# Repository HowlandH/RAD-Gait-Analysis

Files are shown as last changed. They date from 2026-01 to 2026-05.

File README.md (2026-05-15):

# RAD — Running Analysis Device

An affordable (<$60) foot-mounted wearable that tracks running gait metrics in real time and transmits data via Bluetooth Low Energy to an iOS companion app. Built for recreational runners and high school athletes who cannot access professional lab gait analysis ($350-500/session).

**Team:** Hudson Howland and Brantley Field — PLTW Engineering Capstone

---

## Project Status — COMPLETE

| Phase | Status |
|---|---|
| Hardware Assembly | COMPLETE |
| IMU Data Acquisition | COMPLETE |
| Gait Detection Firmware | COMPLETE |
| BLE Communication | COMPLETE |
| iOS Companion App | COMPLETE |
| Enclosure Design & Print | COMPLETE |
| System Integration | COMPLETE |
| Mounting Angle Calibration | COMPLETE |
| Field Testing | COMPLETE |
| Stakeholder Evaluation | COMPLETE |

---

## Hardware

| Component | Part | Cost |
|---|---|---|
| Microcontroller | Arduino Nano 33 BLE Rev2 | ~$25 |
| IMU Sensor | MPU-6050 (GY-521) | ~$3 |
| Power Module | DFRobot MP2636 | ~$10 |
| Battery | 3.7V 700mAh LiPo | ~$8 |
| Enclosure | 3D printed PLA | ~$2 |
| **Total BOM** | | **~$55** |

Enclosure dimensions: 50mm x 40mm x 20mm. Mounts to shoe laces via elastic strap. Snap-fit two-part design.

### Wiring

```
MPU-6050 → Arduino Nano 33 BLE Rev2
  VCC → 3.3V
  GND → GND
  SCL → A5
  SDA → A4

MP2636 Power Module
  VOUT (SYS pin) → Arduino VIN
  GND → Arduino GND
  BAT+ → LiPo red wire
  BAT- → LiPo black wire
  Micro-USB port = charging input only
```

---

## Firmware

Located in `gait_tracker/`. Written in C++ for Arduino Nano 33 BLE Rev2.

### Architecture

| File | Responsibility |
|---|---|
| `gait_tracker.ino` | Main 100Hz loop |
| `config.h` | All constants and thresholds |
| `imu_sensor.h/.cpp` | MPU-6050 init, complementary filter, pitch tracking, mounting angle calibration |
| `gait_detection.h/.cpp` | Foot strike peak detection and heel/midfoot/forefoot classification |
| `stride_length.h/.cpp` | Inverted pendulum stride estimation |
| `cadence.h/.cpp` | Circular buffer cadence calculation |
| `ble_comms.h/.cpp` | ArduinoBLE GATT service and characteristic updates |
| `power_mgmt.h/.cpp` | Battery voltage monitoring |

### Key Algorithms

**Strike detection:** Peak detection on Z-axis acceleration with 200ms debounce. Threshold: 1.5g.

**Strike classification:** Pitch angle at moment of impact:
- Heel: pitch < -15 degrees
- Midfoot: -15 to +5 degrees
- Forefoot: pitch > +5 degrees

**Mounting angle calibration:** On every boot, the firmware samples the device's resting pitch for 3 seconds while mounted on the shoe and stores it as an offset. All subsequent pitch readings subtract this offset so classification thresholds work correctly regardless of mounting angle or shoe geometry.

**Stride length:** Inverted pendulum model: `stride = 4 x legLength x sin(angle/2)`

**Cadence:** Circular buffer of last 30 strike timestamps. Requires 3 minimum strikes before reporting.

### BLE Characteristics

```
Service:     19b10000-e8f2-537e-4f6c-d104768a1214
Stride:      19b10001 (Float, 4 bytes)
Cadence:     19b10002 (UInt16, 2 bytes)
Strike type: 19b10003 (UInt8: 0=Heel, 1=Mid, 2=Fore)
Battery:     00002a19 (UInt8, standard)
```

### Setup

1. Install Arduino IDE
2. Install libraries: ArduinoBLE, Adafruit MPU6050, Adafruit Unified Sensor
3. Open `gait_tracker/gait_tracker.ino`
4. Select board: Arduino Nano 33 BLE
5. Upload — calibration runs automatically on boot

---

## iOS App (GaitTrackerX)

Located in `GaitTrackerX/`. Built in Swift/SwiftUI. Active Xcode project: `GaitTrackerX/GaitTrackerX.xcodeproj`.

### Screens

**Connection Screen** — scans for and connects to the Arduino device with animated BLE pulse rings.

**Live Dashboard** — cadence hero card with color feedback (red/orange/green/blue by performance zone), stride length, distance, duration, pace, and strike type displayed live. Start, pause, and stop run controls.

**Run History** — all past runs with bar charts for cadence trend and distance (last 7 runs) and a donut chart for overall strike type distribution.

**Run Detail** — full metrics for any past run including per-step strike distribution donut chart with counts and percentages, and a cadence analysis bar showing position on the 140-200 spm scale with the 170-180 optimal zone highlighted.

**Share Card** — generates a shareable PNG with dark navy/purple gradient design showing distance, cadence, steps, duration, and strike type.

**Settings** — leg length slider (affects stride calculation), imperial/metric toggle, delete history.

### Key Files

| File | Responsibility |
|---|---|
| `GaitTrackerApp.swift` | App entry point |
| `Managers/BLEManager.swift` | CoreBluetooth scanning, connection, characteristic parsing |
| `Managers/DataManager.swift` | Run history persistence via UserDefaults + JSONEncoder |
| `Models/RunSession.swift` | Active run timer and step accumulation |
| `Models/GaitMetrics.swift` | StrikeType enum and GaitMetrics struct |
| `Views/ConnectionView.swift` | BLE scanning UI |
| `Views/DashboardView.swift` | Live metrics and run controls |
| `Views/HistoryView.swift` | Run history and charts |
| `Views/RunDetailView.swift` | Per-run detailed metrics and graphs |
| `Views/RunSummaryCard.swift` | Shareable PNG card renderer |
| `Views/SettingsView.swift` | User preferences |

---

## Field Testing Results

**Test conducted:** Half-mile walk test, May 1, 2026

| Metric | Result |
|---|---|
| Distance recorded | 1.40 km (actual: 0.84 km, 67% overestimate) |
| Steps counted | 1,157 |
| Duration | 14:10 |
| Cadence | 74 spm |
| Strike classification | Nearly 100% forefoot (caused by mounting angle) |

**Issues identified and resolved:**

1. Forefoot classification bias — the device mounted at a forward angle on the shoe added a static pitch offset that pushed every strike above the +5 degree forefoot threshold. Fixed by adding automatic mounting angle calibration to the firmware startup routine.

2. Stride length overestimation — the inverted pendulum model is calibrated for running gait, not walking. The `STRIDE_CORRECTION_FACTOR` in `config.h` is set to 1.0 and should be tuned against measured track data at running pace.

---

## Stakeholder Evaluation

Feedback gathered from three evaluators:

**Jackson — Peer / Athlete :** Validated the core concept. Suggested adding padding to the enclosure and rounding the corners for comfort. Conditionally willing to use and recommend the device once accuracy is demonstrated.

**Trey — Software Engineer:** Called it an impressive first prototype. Approved of the real-time plus historical data display approach. Raised questions about data privacy and storage that were addressed: all data is stored locally on the user's iPhone with no cloud connection or external transmission.

**Diana — Competitive Runner / Junior Olympic Athlete:** Endorsed the concept for high school runners who cannot afford professional alternatives. Recommended moving to lace mounting over ankle mounting at race pace. Requested accuracy validation against a known device before full endorsement.

---

## Design Specifications

| Priority | Specification | Status |
|---|---|---|
| 1 (Cost) | BOM under $60 | MET — ~$55 |
| 2 (Functionality) | Cadence within 3 spm accuracy | Pending running field test |
| 3 (Size) | Enclosure max 50x40x20mm | MET |
| 4 (Data Rate) | Minimum 100Hz sampling | MET |
| 5 (Battery) | Minimum 3 hours continuous | Pending test |
| 6 (Durability) | IPX3 moisture resistance | Pending test |

---

## Repository Structure

```
RAD-Gait-Analysis/
├── gait_tracker/              # Arduino firmware (active)
│   ├── gait_tracker.ino
│   ├── config.h
│   ├── imu_sensor.h/.cpp      # Includes mounting angle calibration
│   ├── gait_detection.h/.cpp
│   ├── stride_length.h/.cpp
│   ├── cadence.h/.cpp
│   ├── ble_comms.h/.cpp
│   ├── power_mgmt.h/.cpp
│   └── README.md
├── GaitTrackerX/              # iOS app (active Xcode project)
│   └── GaitTrackerX.xcodeproj
├── docs/
│   ├── breadboard_layout.md
│   └── datasheets/
├── test_sketches/             # Standalone hardware test sketches
├── RAD_Project_Briefing.md    # Full project context document
├── CHANGELOG.md
└── README.md
```

---

## Authors

Hudson Howland and Brantley Field — PLTW Engineering Capstone, 2026

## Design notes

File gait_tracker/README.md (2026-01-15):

# Gait Tracker - Arduino Firmware

Arduino firmware for the running gait analysis device.

## Hardware Requirements

- Arduino Nano 33 BLE Rev2
- MPU-6050 6-axis IMU
- MP2636 Power Booster & Charger Module
- 3.7V 700mAh LiPo Battery

## Wiring

```
MPU-6050 → Arduino Nano 33 BLE Rev2
  VCC → 3.3V
  GND → GND
  SCL → A5 (SCL)
  SDA → A4 (SDA)

MP2636 Power Module → Arduino Nano
  5V OUT → VIN
  GND → GND

LiPo Battery → MP2636
  + → BAT+
  - → BAT-
```

## Required Libraries

Install these libraries via Arduino Library Manager:

1. **ArduinoBLE** - For Bluetooth Low Energy communication
2. **Adafruit MPU6050** - For IMU sensor interface
3. **Adafruit Sensor** - Dependency for MPU6050 library
4. **Wire** - I2C communication (built-in)

## Installation

1. Open `gait_tracker.ino` in Arduino IDE
2. Select board: **Arduino Nano 33 BLE** (Tools → Board)
3. Install required libraries
4. Uncomment library includes in relevant files:
   - `imu_sensor.cpp` - MPU6050 library
   - `ble_comms.cpp` - ArduinoBLE library
5. Upload to board

## Configuration

Edit `config.h` to adjust:

- Strike detection threshold
- Cadence buffer size
- BLE service UUIDs
- Battery voltage divider ratio
- Debug mode settings

## Module Overview

### imu_sensor.h/cpp
- Initializes MPU-6050
- Reads accelerometer and gyroscope at 100Hz
- Applies complementary filter for orientation
- Tracks pitch/roll angles and swing angle

### gait_detection.h/cpp
- Detects foot strikes via Z-axis acceleration peaks
- Classifies strike type (heel/midfoot/forefoot) based on pitch angle
- Implements stride state machine

### stride_length.h/cpp
- Estimates stride length using inverted pendulum model
- Formula: `stride_length = 4 * h * sin(θ/2)`
- Supports leg length calibration

### cadence.h/cpp
- Tracks steps per minute using circular buffer
- Maintains rolling average over last 30 strikes
- Target accuracy: ±3 steps/min

### ble_comms.h/cpp
- Advertises as "GaitTracker"
- Implements GATT characteristics for metrics
- Handles connection/disconnection events

### power_mgmt.h/cpp
- Monitors battery voltage via analog pin
- Calculates battery percentage
- Supports low-power mode (TODO)

## Testing

### I2C Scanner Test
Run I2C scanner sketch to verify MPU-6050 at address `0x68`

### Serial Monitor
Set baud rate to **115200** for debug output

### Desktop Testing
1. Tap device on desk at known cadence (use metronome app)
2. Verify strike detection in serial output
3. Tilt device during taps to test strike classification

### BLE Testing
Use "nRF Connect" iOS app to:
- Scan for "GaitTracker" device
- Connect and view characteristics
- Subscribe to notifications

## Calibration

1. Place device on flat surface
2. Power on - calibration runs automatically
3. Verify serial output shows gyroscope offsets
4. Expected accelerometer: Z ≈ 1g, X/Y ≈ 0g

## Troubleshooting

**MPU-6050 not detected:**
- Check I2C wiring (SDA/SCL)
- Run I2C scanner sketch
- Verify 3.3V power connection

**BLE not advertising:**
- Ensure ArduinoBLE library is installed
- Check Serial Monitor for error messages
- Verify board is Arduino Nano 33 BLE Rev2

**Inaccurate strike detection:**
- Adjust `STRIKE_THRESHOLD` in config.h
- Check IMU mounting orientation
- Verify device is secured to shoe

## Next Steps

1. Complete Phase 1: Hardware verification
2. Install required libraries and uncomment includes
3. Test with breadboard setup
4. Proceed to field testing once stable

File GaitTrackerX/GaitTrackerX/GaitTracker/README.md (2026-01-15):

# GaitTracker iOS App

iOS companion app for the running gait tracker device.

## Requirements

- Xcode 14.0+
- Swift 5.7+
- iOS 15.0+
- Physical iOS device (BLE doesn't work in Simulator)

## Project Structure

```
GaitTracker/
├── GaitTrackerApp.swift       # App entry point
├── Views/
│   ├── ConnectionView.swift   # BLE scanning/pairing
│   ├── DashboardView.swift    # Real-time metrics display
│   ├── HistoryView.swift      # Past runs
│   └── SettingsView.swift     # Configuration
├── Models/
│   ├── GaitMetrics.swift      # Data structures
│   └── RunSession.swift       # Run management
├── Managers/
│   ├── BLEManager.swift       # CoreBluetooth wrapper
│   └── DataManager.swift      # Persistence (Core Data)
└── Resources/
    └── Info.plist             # App configuration
```

## BLE Service Specification

### Service UUID
`19b10000-e8f2-537e-4f6c-d104768a1214`

### Characteristics

| Characteristic | UUID | Type | Properties | Description |
|---|---|---|---|---|
| Stride Length | `19b10001-...` | Float (4 bytes) | Read, Notify | Meters |
| Cadence | `19b10002-...` | Uint16 (2 bytes) | Read, Notify | Steps/min |
| Strike Type | `19b10003-...` | Uint8 (1 byte) | Read, Notify | 0=Heel, 1=Mid, 2=Forefoot |
| Battery Level | `00002a19-...` | Uint8 (1 byte) | Read, Notify | Percentage (0-100) |

## Setup Instructions

### 1. Create New Project
1. Open Xcode
2. Create new SwiftUI App project
3. Set minimum deployment target to iOS 15.0
4. Enable CoreBluetooth capability

### 2. Configure Info.plist
Add Bluetooth permissions:
```xml
<key>NSBluetoothAlwaysUsageDescription</key>
<string>This app needs Bluetooth to connect to your GaitTracker device</string>
<key>NSBluetoothPeripheralUsageDescription</key>
<string>This app needs Bluetooth to communicate with your running tracker</string>
```

### 3. Implement BLEManager
```swift
import CoreBluetooth
import Combine

class BLEManager: NSObject, ObservableObject {
    @Published var isScanning = false
    @Published var isConnected = false
    @Published var discoveredDevices: [CBPeripheral] = []
    @Published var currentMetrics = GaitMetrics()

    private var centralManager: CBCentralManager!
    private var connectedPeripheral: CBPeripheral?

    // Service and Characteristic UUIDs
    let gaitServiceUUID = CBUUID(string: "19b10000-e8f2-537e-4f6c-d104768a1214")
    // ... add characteristic UUIDs
}
```

## Key Features

### Dashboard View
- Large cadence display (primary metric)
- Stride length with running average
- Color-coded foot strike indicator:
  - Red = Heel strike (higher impact)
  - Yellow = Midfoot strike (moderate)
  - Green = Forefoot strike (lower impact)
- Distance counter (stride × steps)
- Run timer
- Battery indicator

### Run History
- List of completed runs
- Summary statistics per run
- Charts showing metrics over time
- Tap to view detailed breakdown

### Settings
- **Leg Length Calibration** - Input for stride calculation
- **Units** - Toggle metric/imperial
- **Data Export** - Share runs as CSV

## Data Models

### GaitMetrics
```swift
struct GaitMetrics {
    var strideLength: Float = 0.0      // meters
    var cadence: Int = 0               // steps/min
    var strikeType: StrikeType = .mid
    var batteryLevel: Int = 100        // percentage
    var distance: Float = 0.0          // cumulative meters
    var duration: TimeInterval = 0     // seconds
}

enum StrikeType: UInt8 {
    case heel = 0
    case midfoot = 1
    case forefoot = 2
}
```

### RunSession
```swift
class RunSession: ObservableObject {
    @Published var isActive = false
    @Published var metrics = GaitMetrics()

    var startTime: Date?
    var stepCount: Int = 0

    func start() { }
    func pause() { }
    func stop() { }
    func save() { }
}
```

## Testing

### With nRF Connect App
Before building the full app, test BLE communication:
1. Download "nRF Connect" from App Store
2. Scan for "GaitTracker" device
3. Connect and view services
4. Subscribe to characteristics
5. Verify notifications update correctly

### With Physical Device
1. Build and run on iPhone
2. Power on Arduino device
3. Tap "Scan" in app
4. Connect to "GaitTracker"
5. Simulate foot strikes (tap device on desk)
6. Verify metrics update in real-time

## Development Tasks (Phase 5)

- [ ] Create SwiftUI project
- [ ] Implement BLEManager with CoreBluetooth
- [ ] Create GaitMetrics and RunSession models
- [ ] Build ConnectionView with device scanning
- [ ] Build DashboardView with real-time display
- [ ] Test connection and data parsing
- [ ] Handle disconnect/reconnect gracefully
- [ ] Add error handling and user feedback

## Future Enhancements (Phase 9)

- [ ] Implement HistoryView with Core Data
- [ ] Add SettingsView with calibration
- [ ] Create data visualization charts
- [ ] Implement CSV export
- [ ] Add haptic feedback on strikes
- [ ] Improve UI/UX polish

## Notes

- BLE requires physical iOS device (doesn't work in Simulator)
- Test with Arduino device powered on and advertising
- Connection may take 5-10 seconds initially
- Ensure UUIDs match between firmware and app
- Handle all BLE callbacks on main thread for UI updates

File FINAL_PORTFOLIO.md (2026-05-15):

# Final Portfolio — RAD: Running Analysis Device

**Team:** Hudson Howland and Brantley Field
**Class:** PLTW Engineering Capstone
**Date:** May 2026

---

## 1. Problem Statement

79% of recreational runners are injured each year, and 50-70% of those injuries are overuse injuries directly linked to poor running biomechanics. The primary correctable factor is cadence — the number of steps per minute. Research shows that a 5-10% increase in cadence significantly reduces knee and hip loading. Yet 60% of high school cross-country runners surveyed did not know their own cadence, and 75% expressed concern about past or future injury.

Professional gait analysis costs $350-500 per session and is not accessible to most runners. Existing wearable alternatives either cost $200 or more, use metrics that most runners do not understand, or are no longer available on the market. There is no affordable, accessible solution built specifically for high school athletes and recreational runners.

RAD — the Running Analysis Device — is our solution.

---

## 2. Project Proposal and Design Goals

RAD is a foot-mounted wearable that tracks running gait metrics in real time and sends data wirelessly to an iPhone via Bluetooth Low Energy. It is designed to cost under $60 total and be usable by any runner without any prior technical knowledge.

### Design Specifications

| Priority | Specification | Target |
|---|---|---|
| 1 | Total BOM cost | Under $60 |
| 2 | Cadence accuracy | Within 3 steps/min |
| 3 | Enclosure size | Max 50mm x 40mm x 20mm |
| 4 | Sampling rate | Minimum 100Hz |
| 5 | Battery life | Minimum 3 hours |
| 6 | Moisture resistance | IPX3 |

### Metrics to Track

- Cadence (steps per minute)
- Stride length (meters per step)
- Foot strike type (Heel / Midfoot / Forefoot)
- Distance (cumulative)
- Battery level

---

## 3. Hardware

### Bill of Materials

| Component | Part | Cost |
|---|---|---|
| Microcontroller | Arduino Nano 33 BLE Rev2 | ~$25 |
| IMU Sensor | MPU-6050 (GY-521) | ~$3 |
| Power Module | DFRobot MP2636 | ~$10 |
| Battery | 3.7V 700mAh LiPo | ~$8 |
| Enclosure | 3D printed PLA | ~$2 |
| **Total** | | **~$55** |

Design specification met: BOM is under $60.

### Wiring

```
MPU-6050 → Arduino Nano 33 BLE Rev2
  VCC → 3.3V
  GND → GND
  SCL → A5
  SDA → A4

MP2636 Power Module
  VOUT → Arduino VIN (5V regulated)
  GND → Arduino GND
  BAT+ → LiPo red wire
  BAT- → LiPo black wire
  Micro-USB port = charging input only
```

### Enclosure

3D printed in blue PLA. Dimensions: 50mm x 40mm x 20mm (meets design spec). Snap-fit two-part design for easy access to internals. Mounts to shoe laces via elastic strap.

---

## 4. Firmware

Written in C++ for Arduino Nano 33 BLE Rev2. Modular architecture across 6 files.

### How It Works

**Step 1 — Startup calibration:** The device samples the IMU for approximately 3 seconds on boot. First it removes gyroscope bias by averaging 100 samples at rest. Then it warms up the pitch filter and records the device's resting pitch angle from the shoe mounting position. This offset is stored and subtracted from all future pitch readings so classification thresholds work correctly regardless of how the device sits on the shoe.

**Step 2 — 100Hz sampling loop:** The main loop runs every 10ms. Each cycle reads the MPU-6050 accelerometer and gyroscope and updates the pitch angle estimate using a complementary filter (96% gyroscope, 4% accelerometer).

**Step 3 — Foot strike detection:** When Z-axis acceleration exceeds 1.5g and begins to decelerate, a foot strike is recorded. A 200ms debounce window prevents double-counting.

**Step 4 — Strike classification:** At the moment of impact, the corrected pitch angle determines strike type:
- Heel: below -15 degrees
- Midfoot: -15 to +5 degrees
- Forefoot: above +5 degrees

**Step 5 — Stride length:** The maximum swing angle during each stride is tracked. At each foot strike, stride length is calculated using the inverted pendulum model: `stride = 4 x legLength x sin(angle/2)`.

**Step 6 — Cadence:** A circular buffer stores the timestamps of the last 30 foot strikes. Cadence is calculated from the span of those timestamps. A minimum of 3 strikes is required before cadence is reported.

**Step 7 — BLE transmission:** After each foot strike, four BLE characteristics are updated: stride length (Float), cadence (UInt16), strike type (UInt8), and battery level (UInt8). The iPhone app receives these notifications in real time.

---

## 5. iOS App (GaitTracker)

Built in Swift/SwiftUI. Runs on iPhone via Bluetooth. Tested on physical hardware.

### Connection Screen
Scans for nearby Arduino devices. Animated pulsing rings provide visual feedback while scanning.

### Live Dashboard
Displays cadence, stride length, distance, duration, pace, and strike type in real time. The cadence card changes color based on performance: red (below 160 spm), orange (160-169), green (170-180 optimal), blue (above 180). Run start, pause, and stop controls.

### Run History
Shows all past runs as cards. Bar charts display cadence trend and distance for the last 7 runs. A donut chart shows overall strike type distribution across all saved runs. Charts appear automatically once 2 or more runs exist.

### Run Detail
Opens from any run card. Shows all metrics for that run. Includes a per-step strike distribution donut chart with step counts and percentages, and a cadence analysis bar that shows where the run falls on a 140-200 spm scale with the 170-180 optimal zone highlighted in green.

### Share Card
Generates a shareable PNG image for each run. Dark navy and purple gradient design. Shows distance, cadence, steps, duration, and strike type. Shared via the iOS system share sheet.

### Settings
Leg length slider from 0.6 to 1.1 meters (affects stride calculation accuracy). Imperial and metric unit toggle. Delete all history option.

---

## 6. Testing Results

### Field Test — Half-Mile Walk Test, May 1, 2026

| Metric | Recorded | Actual | Notes |
|---|---|---|---|
| Distance | 1.40 km | 0.84 km | 67% overestimate |
| Steps | 1,157 | — | Confirmed counting |
| Duration | 14:10 | — | Confirmed timing |
| Cadence | 74 spm | — | Expected for walking |
| Strike type | 100% Forefoot | Mixed | Mounting angle bias |

### Issues Found and Resolved

**Issue 1 — Forefoot classification bias**
The device was mounted at a forward angle on the shoe, adding a static pitch offset that pushed every detected pitch reading above the +5 degree forefoot threshold. Every step was classified as forefoot regardless of actual strike type.

Resolution: A mounting angle calibration routine was added to the firmware startup. The device now automatically measures its resting pitch angle when mounted on the shoe and subtracts that offset from all subsequent readings. This runs on every boot with no user input required.

**Issue 2 — Stride length overestimation**
The inverted pendulum model overestimated distance by approximately 67% during the walk test. The `STRIDE_CORRECTION_FACTOR` constant in the firmware is set to 1.0 and has not been tuned against real data.

Resolution: This requires a measured running test on a track of known distance. The correction factor should be adjusted until the device output matches the true distance. This is planned as the next field test.

### Design Specification Status

| Specification | Status |
|---|---|
| BOM under $60 | MET — approximately $55 |
| Enclosure max 50x40x20mm | MET |
| 100Hz sampling rate | MET |
| Cadence within 3 spm | Pending running field test |
| Battery minimum 3 hours | Pending test |
| IPX3 moisture resistance | Pending test |

---

## 7. Stakeholder Evaluation

Three external evaluators reviewed the prototype and provided structured feedback.

### Jackson — Peer / Cross-Country Runner

Validated the core concept, saying the device would help runners know when they are doing well or poorly, which would help change running form for the better. Primary concern was the physical enclosure — recommended adding padding and rounding the corners so it does not feel like a plastic box on the ankle. Willing to use and recommend the device once accuracy is demonstrated.

### Trey — Software Engineer

Called it an impressive first prototype and approved the data display approach of real-time metrics plus historical trend graphs. Raised questions about data privacy and storage. This was addressed: all data is stored locally on the user's iPhone using iOS storage with no cloud connection, no account required, and no external transmission of any kind. Said he would use the device if it proved reliable over extended use.

### Diana — Competitive Runner / Junior Olympic Athlete

Endorsed the concept strongly for high school runners who cannot access professional alternatives, noting the sub-$60 price point as a genuine competitive advantage. Recommended moving from ankle mounting to lace mounting, consistent with how professional pods like Stryd and Garmin Running Dynamics are worn. Asked for accuracy validation against a known device before full endorsement.

### Summary

All three stakeholders validated the core problem and confirmed the concept addresses it effectively. The recurring feedback themes were: improve the enclosure comfort, validate accuracy with a side-by-side comparison test, and confirm data stays private on the user's device.

---

## 8. Improvement Plans

### Based on Testing

The stride correction factor needs to be tuned against real running data on a track of known distance. The mounting angle calibration added during testing resolved the forefoot bias and should be extended to store the calibration value in device memory so the startup time is reduced.

### Based on External Evaluation

The enclosure should be redesigned with rounded edges, foam or silicone padding on contact surfaces, and a lower profile. The default mounting position should move to the lace top rather than the ankle based on evaluator feedback from the competitive runner. A short privacy statement should be added to the app Settings screen to address data security questions proactively.

### Based on Internal Evaluation

Field testing should have been scheduled immediately after the first successful BLE connection rather than at the end of the project. Hardware subsystems should be tested in isolation with a multimeter before being combined. The data model should be fully designed before any persistence code is written to avoid compatibility work mid-project.

### What to Do Differently

User interviews should happen before the enclosure is designed so feedback directly shapes hardware decisions. A ground truth test protocol should be defined before firmware is written. The BLE data format should be finalized first so firmware and app can be developed independently in parallel.

### Recommendations for a Similar Project

Test each hardware component in isolation before combining. Confirm IMU output in the serial monitor before touching BLE. Verify power module voltage with a multimeter before connecting anything. Build the iOS app against simulated data before hardware is ready. Decide on a mounting position at the start and do not change it. Schedule a field test date early and treat it as a hard deadline.

---

## 9. Competition Comparison

| Product | Price | Problem |
|---|---|---|
| RunScribe | $600 | Out of business |
| Stryd 5.0 | $200 | Uses power metric most runners do not understand |
| Lab gait analysis | $350-500/session | Not portable, not accessible |
| **RAD** | **~$55** | **Affordable, portable, accessible** |

---

## 10. Key Statistics

- 79% of recreational runners are injured annually (NIH)
- 50-70% of running injuries are overuse injuries from poor biomechanics
- 5-10% cadence increase significantly reduces knee and hip loading
- 170-180 spm is the widely accepted optimal cadence range
- $350-500 average cost for a single professional lab gait analysis session
- 60% of high school cross-country runners surveyed did not know their cadence
- 75% of those same runners expressed concern about past or future injury

---

## 11. Reflection

RAD began as a response to a real and well-documented problem: most runners get injured, most injuries are preventable, and the tools to prevent them are out of reach for high school athletes. The goal was to build something that actually works, costs less than a pair of running shoes, and fits in a pocket.

The hardware came together through iteration. The power module required troubleshooting a reversed JST connector polarity and understanding the onboard boost converter behavior. The firmware required careful ordering of operations — specifically that stride calculation must happen before the swing angle is reset, and that the peak detection logic depends on tracking acceleration across multiple samples. These were the kinds of bugs that only appear when the device is actually running on hardware.

The iOS app grew significantly beyond the original scope. What started as a basic dashboard became a full history system with charts, a per-run detail view with strike distribution graphs, a cadence analysis bar, and a shareable summary card. Each addition came from thinking about what a runner would actually want to see after a run.

The most important lesson from this project is that field testing should not be the last step. The walk test revealed two significant issues — the forefoot bias and the stride overestimate — that would not have been found at a desk. Both were fixable, but finding them earlier would have allowed more time to validate the fixes. Building a device is one thing; proving that it works is another, and that proof only comes from running in it.

---

*PLTW Engineering Capstone — Hudson Howland and Brantley Field — 2026*

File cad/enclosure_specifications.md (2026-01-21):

# Gait Tracker Enclosure - Inventor CAD Specifications

Complete dimensional specifications for building the enclosure in Autodesk Inventor.

## Component Dimensions (All measurements in mm)

### Arduino Nano 33 BLE Rev2
- **Length:** 45.0 mm
- **Width:** 18.0 mm
- **Height:** 5.0 mm (PCB + components)
- **Mounting holes:** 2.0 mm diameter, located 2.0 mm from each corner
- **Micro-USB connector:**
  - Width: 8.0 mm
  - Height: 3.0 mm
  - Protrusion from board edge: 6.0 mm
  - Located: Centered on short edge

### MPU-6050 (GY-521 Breakout)
- **Length:** 21.0 mm
- **Width:** 16.0 mm
- **Height:** 3.0 mm (PCB + sensor)
- **Mounting holes:** 2.0 mm diameter, located at corners

### MP2636 Power Module (DFRobot DFR0446)
- **Length:** 28.0 mm
- **Width:** 18.0 mm
- **Height:** 4.0 mm
- **Micro-USB connector (charging input):**
  - Width: 8.0 mm
  - Height: 3.0 mm
  - Located: Side edge, centered
- **USB-A connector (5V output):**
  - Width: 14.0 mm
  - Height: 7.0 mm
  - Located: Same side as Micro-USB, opposite end

### 3.7V 700mAh LiPo Battery
- **Length:** 50.0 mm
- **Width:** 34.0 mm
- **Height:** 6.0 mm

## Enclosure Design Parameters

### General Settings
- **Wall thickness:** 2.0 mm
- **Clearance around components:** 1.0 mm
- **Corner radius:** 3.0 mm (external), 2.0 mm (internal)
- **Mounting post diameter:** 3.0 mm
- **Screw hole diameter:** 2.0 mm (for M2 screws)
- **Lid lip depth:** 1.5 mm

### Calculated Overall Dimensions
- **Internal cavity:**
  - Length: 52.0 mm (battery length + 2mm clearance)
  - Width: 58.0 mm (18 + 16 + 18 + 6mm clearance)
  - Height: 8.0 mm (max component height + 2mm clearance)

- **External dimensions:**
  - Length: 56.0 mm
  - Width: 62.0 mm
  - Height (bottom): 10.0 mm
  - Height (lid): 2.0 mm

## Inventor Modeling Instructions

### Part 1: Enclosure Bottom

#### Step 1: Create Base Sketch (XY Plane)
1. Create new part file
2. Start sketch on XY plane
3. Draw rectangle: 56.0 mm × 62.0 mm, centered on origin
4. Fillet all corners with 3.0 mm radius
5. Finish sketch

#### Step 2: Extrude Base
1. Extrude sketch: 10.0 mm (upward, positive Z)
2. Result: Solid box with rounded corners

#### Step 3: Create Internal Cavity
1. Start sketch on top face
2. Offset internal edge by 2.0 mm (inward)
3. Fillet internal corners with 2.0 mm radius
4. Finish sketch
5. Extrude cut: 8.0 mm depth (downward into solid)
6. Result: Hollow box with 2.0 mm walls and 2.0 mm floor

#### Step 4: Micro-USB Access Port (Arduino)
1. Start sketch on front face (short edge)
2. Draw rectangle:
   - Width: 8.0 mm
   - Height: 3.0 mm
   - Position:
     - Centered horizontally
     - 3.0 mm from top edge
     - 3.0 mm from internal floor (5.0 mm from bottom)
3. Extrude cut: Through wall (2.0 mm depth)

#### Step 5: Micro-USB Access Port (MP2636)
1. Start sketch on side face (long edge)
2. Draw rectangle:
   - Width: 8.0 mm
   - Height: 3.0 mm
   - Position: Calculate based on MP2636 placement (see component layout below)
3. Extrude cut: Through wall

#### Step 6: USB-A Access Port (MP2636)
1. Start sketch on same side face
2. Draw rectangle:
   - Width: 14.0 mm
   - Height: 7.0 mm
   - Position: Below Micro-USB port
3. Extrude cut: Through wall

#### Step 7: Mounting Posts
Create cylindrical posts for each component mounting hole:

**Post specifications:**
- Diameter: 3.0 mm
- Height: 7.0 mm (from floor to component level)
- Screw hole: 2.0 mm diameter, through center

**Arduino posts (4 positions):**
- Origin reference: Front-left corner of internal cavity
- Post 1: X=4.0, Y=4.0
- Post 2: X=47.0, Y=4.0
- Post 3: X=4.0, Y=18.0
- Post 4: X=47.0, Y=18.0

**MPU-6050 posts (2 positions):**
- Origin reference: Same
- Post 1: X=4.0, Y=24.0
- Post 2: X=23.0, Y=38.0

**MP2636 posts (2 positions):**
- Origin reference: Same
- Post 1: X=4.0, Y=44.0
- Post 2: X=30.0, Y=60.0

#### Step 8: Lid Retention Lip
1. Start sketch on top edge of cavity
2. Create rectangle offset 1.5 mm inward from cavity edge
3. Extrude upward: 2.0 mm
4. Shell feature: 2.0 mm wall thickness (hollow out the lip)

#### Step 9: Corner Screw Bosses (for lid attachment)
Create 4 cylindrical bosses:
- Position: 4.0 mm from each external corner
- Diameter: 4.0 mm
- Height: Full height (10.0 mm from floor)
- Countersunk hole:
  - 2.0 mm diameter through
  - 4.0 mm diameter × 1.0 mm deep countersink at bottom

### Part 2: Enclosure Lid

#### Step 1: Create Base Sketch
1. Create new part file
2. Start sketch on XY plane
3. Draw rectangle: 56.0 mm × 62.0 mm, centered on origin
4. Fillet all corners with 3.0 mm radius
5. Finish sketch

#### Step 2: Extrude Lid
1. Extrude sketch: 2.0 mm upward
2. Result: Flat lid with rounded corners

#### Step 3: Corner Screw Holes
Create 4 screw holes:
- Position: 4.0 mm from each corner (match bottom screw bosses)
- Diameter: 2.2 mm (clearance for M2 screw)
- Depth: Through all (2.0 mm)

#### Step 4: Ventilation Slots
Create 5 rectangular slots for ventilation:
- Dimensions: 2.0 mm wide × 20.0 mm long
- Spacing: 7.0 mm center-to-center
- Position: Centered on lid
- Depth: Through all

### Component Layout (Internal Cavity Reference)

All positions measured from front-left corner (0,0) of internal cavity floor:

#### Arduino Nano 33 BLE Rev2
- Position: X=2.0, Y=2.0
- Orientation: USB connector facing front edge
- Elevation: 7.0 mm above floor (on mounting posts)

#### MPU-6050
- Position: X=2.0, Y=22.0
- Orientation: Sensor facing up
- Elevation: 7.0 mm above floor

#### MP2636 Power Module
- Position: X=2.0, Y=42.0
- Orientation: USB connectors facing side edge
- Elevation: 7.0 mm above floor

#### LiPo Battery
- Position: X=30.0, Y=14.0
- Orientation: Flat, wires toward components
- Elevation: 2.0 mm above floor (rests on floor with clearance)

## Assembly Hardware

### Required Screws
- **Component mounting:** 8× M2 × 10mm screws (for mounting posts)
- **Lid attachment:** 4× M2 × 8mm screws (for corner bosses)

### Assembly Sequence
1. Install Arduino Nano on mounting posts (4 screws)
2. Install MPU-6050 on mounting posts (2 screws)
3. Install MP2636 on mounting posts (2 screws)
4. Place battery in cavity
5. Route wires as needed
6. Attach lid (4 screws)

## Material Recommendations

### 3D Printing
- **Material:** PLA or PETG
- **Layer height:** 0.2 mm
- **Wall thickness:** 3 perimeters minimum
- **Infill:** 20%
- **Supports:** None required (design is support-free)

### CNC Machining
- **Material:** ABS plastic or aluminum
- **Tolerances:** ±0.1 mm

## Design Notes

1. **USB Access:** All USB ports are accessible from the exterior for charging and programming
2. **Ventilation:** Lid slots allow heat dissipation from Arduino and power module
3. **Wire Routing:** Space between battery and components allows for wire routing
4. **Mounting:** All components are elevated 7mm above floor to allow wire routing underneath
5. **Serviceability:** Lid is easily removable for repairs and modifications

## Optional Enhancements

### Belt Clip
Add to back face:
- Position: Centered on long edge
- Style: Integrated clip or mounting holes for commercial clip
- Dimensions: 25mm wide × 10mm tall

### Status LED Window
Add to lid:
- Position: Above Arduino location
- Dimensions: 3mm diameter clear window
- Purpose: View Arduino onboard LED

### Strap Attachment Points
Add to each end:
- Position: Centered on short edges
- Style: 10mm diameter holes or loops
- Purpose: Attach elastic strap for mounting to leg

## Drawing Views for Inventor

### Recommended Views for Documentation
1. **Isometric view** - Overall assembly
2. **Top view** - Component layout
3. **Front section view (A-A)** - Show internal cavity and mounting posts
4. **Side section view (B-B)** - Show USB access ports
5. **Exploded view** - Assembly sequence

## File Organization

Suggested file naming:
- `gait_tracker_bottom.ipt` - Enclosure bottom
- `gait_tracker_lid.ipt` - Enclosure lid
- `gait_tracker_assembly.iam` - Assembly file
- `gait_tracker_drawing.idw` - Engineering drawing

---

**Created:** 2026-01-21
**Project:** RAD Gait Analysis Tracker
**Revision:** 1.0

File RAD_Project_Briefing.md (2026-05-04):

# RAD Project Briefing — Running Analysis Device

## What It Is
A foot-mounted wearable that tracks running gait metrics in real time and sends data wirelessly to an iPhone app via Bluetooth Low Energy (BLE). Built for recreational runners and high school athletes who cannot afford professional lab gait analysis ($350-500/session). Total device cost is under $60.

## Team
- Hudson Howland and Brantley Field
- PLTW Engineering Capstone

---

## Hardware Components
| Component | Part | Cost |
|---|---|---|
| Microcontroller | Arduino Nano 33 BLE Rev2 | ~$25 |
| IMU Sensor | MPU-6050 (GY-521) | ~$3 |
| Power Module | DFRobot MP2636 | ~$10 |
| Battery | 3.7V 700mAh LiPo | ~$8 |
| Enclosure | 3D printed PLA | ~$2 |
| **Total BOM** | | **~$55** |

Enclosure dimensions: 50mm x 40mm x 20mm. Mounts to shoe laces via elastic strap. Snap-fit two-part design for easy access to internals.

---

## What It Measures
1. **Cadence** — steps per minute (optimal: 170-180 spm)
2. **Stride length** — meters per step using inverted pendulum model
3. **Foot strike type** — Heel / Midfoot / Forefoot classified by pitch angle at moment of impact
4. **Distance** — cumulative, calculated from stride length
5. **Battery level** — percentage remaining

---

## How It Works (Firmware)
- Samples IMU at 100Hz
- Detects foot strikes via Z-axis acceleration peak detection with 200ms debounce to prevent false positives
- Classifies strike type by pitch angle at impact: Heel = below -15 degrees, Forefoot = above +5 degrees, Midfoot = between
- Calculates stride length using inverted pendulum model: stride = 4 x legLength x sin(angle/2)
- Cadence calculated from circular buffer of recent strike timestamps
- Transmits 4 BLE characteristics to iPhone:
  - Stride length (Float, 4 bytes)
  - Cadence (UInt16, 2 bytes)
  - Strike type (UInt8: 0=Heel, 1=Midfoot, 2=Forefoot)
  - Battery level (UInt8, percentage)

---

## iOS App (GaitTracker)
Built in Swift/SwiftUI. Runs on iPhone via Bluetooth. Features:

**Connection Screen**
- Scans for and connects to the Arduino device
- Animated pulsing Bluetooth rings while scanning

**Live Dashboard**
- Cadence hero card — color changes by performance (red = low, orange = approaching, green = optimal, blue = high)
- Stride length, distance, duration, pace, strike type displayed live
- Start / Pause / Stop run controls

**History Screen**
- Run history cards showing all past runs
- Bar charts: cadence trend and distance per run (last 7 runs)
- Donut chart: strike type distribution across all runs
- Charts appear automatically when 2 or more runs exist

**Run Detail Screen**
- Opens when you tap any run card
- Shows all metrics for that specific run
- Per-step strike distribution donut chart with counts and percentages
- Cadence analysis bar showing where the run lands on the 140-200 spm scale with the 170-180 optimal zone highlighted
- Performance assessment message

**Share Card**
- Generates a shareable PNG image for each run
- Dark navy/purple gradient design
- Shows distance, cadence, steps, duration, strike type

**Settings**
- Leg length slider (affects stride calculation accuracy)
- Imperial/metric toggle
- Delete all history

---

## Design Specifications
| Priority | Specification | Status |
|---|---|---|
| 1 (Cost) | BOM under $60 | MET |
| 2 (Functionality) | Cadence within 3 spm accuracy | Pending field test |
| 3 (Size) | Enclosure max 50x40x20mm | MET |
| 4 (Data Rate) | Minimum 100Hz sampling | MET |
| 5 (Battery) | Minimum 3 hours continuous | Pending test |
| 6 (Durability) | IPX3 moisture resistance | Pending test |

---

## Current Status
- **Firmware:** Fully working. BLE transmitting all 4 characteristics confirmed.
- **iOS App:** Built and running on physical iPhone. All features working.
- **Enclosure:** 3D printed in blue PLA. Snap-fit design complete.
- **Field Testing:** NOT yet completed. No real cadence accuracy numbers yet.
- **Pending:** Battery life test, waterproofing test, cadence accuracy vs metronome

---

## Competition
| Product | Price | Problem |
|---|---|---|
| RunScribe | $600 | Out of business |
| Stryd 5.0 | $200 | Uses "power" metric most runners don't understand |
| Lab gait analysis | $350-500/session | Not portable, not accessible |
| **RAD** | **<$60** | **Our solution** |

---

## Key Statistics
- **79%** of recreational runners get injured annually (NIH)
- **50-70%** of running injuries are overuse injuries from poor biomechanics
- **20-40x** increased injury risk when jumping mileage without fixing form
- **170-180 spm** is the widely accepted optimal cadence range
- **5-10%** cadence increase significantly reduces knee and hip loading (Journal of Orthopaedic & Sports Physical Therapy)
- **$350-500** average cost for a single professional lab gait analysis session
- **60%** of high school cross-country runners surveyed didn't know their cadence
- **75%** of those same runners expressed concern about past or future injury

---

## What the Existing Slides Are Missing
- Screenshots of the working iOS app (dashboard, history charts, run detail, share card)
- Photos of the final assembled device on a shoe
- Actual field test data (cadence accuracy numbers, battery life)
- A clear before/after story showing how RAD fixes the problem
- A compelling cost comparison visual ($350 lab vs $60 RAD)
- Demo or video of the device working in real time

---

## Suggested Slide Structure (16 slides)
1. Title — "RAD: The Running Analysis Device"
2. The Problem — 79% stat as hero number
3. Why Runners Get Hurt — cadence / overstriding / no feedback
4. Current Solutions All Fail — competition comparison
5. Our Solution — one sentence + device photo
6. Who It's For — stakeholders
7. Key Statistics — large visual callouts
8. How It Works — system diagram (sensor → BLE → iPhone)
9. The Hardware — component photo + BOM table
10. The App — screenshots of dashboard and history
11. Design Specifications — table
12. Prototype Evolution — first (red box) to final (blue box)
13. Testing Plan — checklist
14. Safety — electrical / physical / software
15. Future Improvements — top 6 items, 3 categories
16. References

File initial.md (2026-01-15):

# Running Gait Tracker - Implementation Plan

## Project Context

### Problem Statement (from slides 14-17)
- **Target Users**: High school cross-country runners and recreational athletes
- **Market Gap**: 60% of runners unaware of their cadence, 75% concerned about injury
- **Cost Barrier**: Professional gait analysis costs $350-500 per session
- **Injury Prevention**: 79% of runners sustain injuries annually; 50-70% are overuse injuries from poor biomechanics
- **Solution**: Affordable (<$60) device providing real-time cadence, stride length, and foot strike feedback

### Research Justification
- Optimal cadence: 170-180 steps/min reduces impact forces
- 5-10% cadence increase significantly reduces knee/hip stress (Journal of Orthopaedic & Sports Physical Therapy)
- Peak vertical ground reaction force: 2.5-3.5× body weight during running
- Existing products (RunScribe: $600, Stryd: $200) too expensive for target market

### Competitive Analysis
**RunScribe**: $600, out of business, small/compact but expensive
**Stryd**: $200, highly accurate but uses confusing "power" metrics
**Patent US7901325B2**: Multi-sensor harness system - clunky, sensors prone to shifting
**Our Approach**: Simple single-sensor design, accessible price point, focus on core metrics

## Project Overview
Build a foot-mounted running gait analysis device that tracks:
- **Stride length** (distance per step)
- **Foot strike patterns** (Heel/Midfoot/Forefoot classification)
- **Cadence** (steps per minute) - Target: within 3-step margin of error

Data transmitted in real-time via Bluetooth Low Energy to iOS companion app.

### Design Specifications (from slides 14-17)
**Priority 1 (Cost)**: Total BOM must be less than $60.00
**Priority 2 (Functionality)**: Measure and report Cadence within a 3-step margin of error
**Priority 3 (Portability/Size)**: Enclosure max dimensions: 50mm × 40mm × 20mm
**Priority 4 (Data Rate)**: Minimum 100 Hz sampling rate for accurate peak detection
**Priority 5 (Battery Life)**: Minimum 3 hours continuous operation on single charge
**Priority 6 (Durability)**: Withstand 35-100°F and light moisture (IPX3 equivalent)

## Hardware Architecture

### Components Used
1. **Arduino Nano 33 BLE Rev2** - Main microcontroller
   - Built-in BLE for iOS communication
   - 64 MHz ARM Cortex-M4 processor
   - Built-in 6-axis IMU (LSM9DS1), but we'll use external MPU-6050 for consistency

2. **MPU-6050** - 6-axis IMU (3-axis accelerometer + 3-axis gyroscope)
   - Connected via I2C to Arduino Nano
   - Primary sensor for gait detection

3. **MP2636 Power Booster & Charger Module**
   - Manages 3.7V 700mAh LiPo battery
   - Provides stable 5V to Arduino Nano
   - Charging circuit for USB recharging

4. **3.7V 700mAh LiPo Battery**
   - Target runtime: 1-2 hours (typical run duration)

### Components NOT Used
- **ESP32**: Not needed (Arduino Nano BLE handles BLE communication)
- **HC-05**: Incompatible with iOS (requires BLE, not Bluetooth Classic)

### Wiring Diagram
```
MPU-6050 → Arduino Nano 33 BLE Rev2
  VCC → 3.3V
  GND → GND
  SCL → A5 (SCL)
  SDA → A4 (SDA)

MP2636 Power Module → Arduino Nano
  5V OUT → VIN
  GND → GND

LiPo Battery → MP2636
  + → BAT+
  - → BAT-

USB-C (charging) → MP2636 USB input
```

## Firmware Architecture (Arduino)

### Core Libraries Required
1. **ArduinoBLE** - Bluetooth Low Energy communication
2. **MPU6050** (Adafruit or I2Cdevlib) - IMU sensor interface
3. **Wire** - I2C communication

### Software Modules

#### 1. IMU Data Acquisition Module
**File**: `imu_sensor.ino` or `imu_sensor.h/cpp`

**Responsibilities**:
- Initialize MPU-6050 (set sensitivity ranges, calibrate)
- Read accelerometer (X, Y, Z) at 100Hz sampling rate
- Read gyroscope (X, Y, Z) at 100Hz
- Apply complementary or Kalman filter for orientation estimation
- Detect motion vs. stationary states

**Key Functions**:
```cpp
void initIMU()
void calibrateIMU()
void readIMUData(float &ax, float &ay, float &az, float &gx, float &gy, float &gz)
void updateOrientation()
```

#### 2. Gait Detection Module
**File**: `gait_detection.ino` or `gait_detection.h/cpp`

**Responsibilities**:
- **Foot Strike Detection**: Detect impact events using accelerometer Z-axis peaks
- **Strike Classification**: Analyze acceleration pattern to classify as Heel/Mid/Forefoot
  - Heel strike: Sharp peak in vertical acceleration, foot angle pitched backward
  - Midfoot strike: Moderate peak, relatively flat foot angle
  - Forefoot strike: Gradual peak, foot angle pitched forward
- **Stride Segmentation**: Mark beginning/end of each stride cycle
- **Ground Contact Time**: Measure time foot is on ground vs. in air

**Key Algorithms**:
```cpp
bool detectFootStrike(float az)  // Threshold-based peak detection
StrikeType classifyStrike(float ax, float ay, float az, float pitch)
void updateStrideState()
```

**Strike Classification Logic**:
- Use accelerometer Z-axis (vertical) magnitude to detect impact
- Use pitch angle (from gyro integration) at impact to determine strike type:
  - Pitch < -15°: Heel strike
  - Pitch -15° to +5°: Midfoot strike
  - Pitch > +5°: Forefoot strike

#### 3. Stride Length Estimation Module
**File**: `stride_length.ino` or `stride_length.h/cpp`

**Responsibilities**:
- Estimate stride length using double integration method or empirical models
- **Method 1 (Recommended)**: Inverted pendulum model
  - `stride_length = 4 * h * sin(θ/2)` where h = leg length, θ = max swing angle
  - Estimate swing angle from gyroscope integration during swing phase
- **Method 2**: Double integration with drift correction
  - Integrate acceleration during swing phase
  - Apply high-pass filter to remove drift
  - Reset integration at each foot strike

**Key Functions**:
```cpp
float calculateStrideLength(float maxSwingAngle)
void updateSwingPhase(float gz)
```

**Calibration**:
- User inputs leg length (hip to ground) in app
- Optional: Auto-calibration by having user run known distance

#### 4. Cadence Calculation Module
**File**: `cadence.ino` or `cadence.h/cpp`

**Responsibilities**:
- Count steps per minute
- Maintain rolling average over last 30 seconds
- Update every stride

**Key Functions**:
```cpp
void incrementStepCount()
float calculateCadence()  // Steps per minute
void updateCadenceWindow()
```

**Algorithm**:
- Track timestamps of last N foot strikes (circular buffer)
- Cadence = (N-1) / (timestamp_last - timestamp_first) * 60

#### 5. BLE Communication Module
**File**: `ble_comms.ino` or `ble_comms.h/cpp`

**Responsibilities**:
- Advertise BLE service with device name "GaitTracker"
- Define custom GATT service and characteristics
- Transmit gait metrics to connected iOS app
- Handle connection/disconnection events
- Implement battery level characteristic

**BLE Service Design**:
```
Service UUID: 0x181A (Environmental Sensing) or custom UUID

Characteristics:
1. Stride Length (UUID: custom)
   - Type: Float (4 bytes)
   - Properties: Read, Notify
   - Unit: meters

2. Cadence (UUID: custom)
   - Type: Uint16 (2 bytes)
   - Properties: Read, Notify
   - Unit: steps/min

3. Foot Strike Type (UUID: custom)
   - Type: Uint8 (1 byte)
   - Properties: Read, Notify
   - Values: 0=Heel, 1=Mid, 2=Forefoot

4. Real-time IMU (UUID: custom) [Optional for debugging]
   - Type: 6 x Float (24 bytes)
   - Properties: Notify
   - Data: ax, ay, az, gx, gy, gz

5. Battery Level (UUID: 0x2A19)
   - Type: Uint8 (1 byte)
   - Properties: Read, Notify
   - Unit: percentage (0-100)
```

**Update Rate**: Send notifications every stride (cadence/stride) or every 1 second (averaged metrics)

#### 6. Power Management Module
**File**: `power_mgmt.ino` or `power_mgmt.h/cpp`

**Responsibilities**:
- Monitor battery voltage via analog pin (voltage divider from LiPo)
- Enter low-power mode when stationary (no motion detected for 30 seconds)
- Wake on motion interrupt from MPU-6050
- Target runtime: 1-2 hours continuous operation

**Power Optimization Strategies**:
- Reduce BLE advertising interval when not connected
- Lower IMU sampling rate during idle
- Disable LEDs
- Use MPU-6050 motion interrupt for wake-up

**Key Functions**:
```cpp
void initPowerManagement()
uint8_t getBatteryPercent()
void enterLowPowerMode()
void wakeFromMotion()
```

### Main Loop Structure
```cpp
void setup() {
  initIMU();
  initBLE();
  initPowerManagement();
  calibrateIMU();
}

void loop() {
  // Read sensors at 100Hz
  readIMUData(ax, ay, az, gx, gy, gz);

  // Process gait
  if (detectFootStrike(az)) {
    StrikeType strike = classifyStrike(ax, ay, az, pitch);
    float stride = calculateStrideLength(maxSwingAngle);
    incrementStepCount();

    // Update BLE characteristics
    updateBLEMetrics(stride, strike);
  }

  // Update cadence every second
  if (millis() - lastCadenceUpdate > 1000) {
    float cadence = calculateCadence();
    updateBLECadence(cadence);
    lastCadenceUpdate = millis();
  }

  // Power management
  if (isStationary() && millis() - lastMotion > 30000) {
    enterLowPowerMode();
  }

  delay(10);  // 100Hz loop
}
```

## iOS Companion App Architecture

### Technology Stack
- **Language**: Swift
- **Framework**: SwiftUI for UI
- **BLE**: CoreBluetooth framework
- **Minimum iOS**: 15.0

### App Features

#### 1. BLE Connection Screen
- Scan for "GaitTracker" device
- Display connection status
- Auto-reconnect on disconnect

#### 2. Real-Time Metrics Dashboard
**Primary Display**:
- **Cadence**: Large number display (steps/min) with trend graph
- **Stride Length**: Current and average (meters)
- **Foot Strike Pattern**: Visual indicator (heel/mid/forefoot) with color coding
  - Heel: Red (higher impact)
  - Midfoot: Yellow (moderate)
  - Forefoot: Green (lower impact)
- **Distance**: Cumulative distance (stride_length × step_count)
- **Duration**: Run timer
- **Battery Level**: Icon in top corner

#### 3. Run History
- Save completed runs to Core Data or CloudKit
- Display past runs with summary statistics
- Graphs of metrics over time

#### 4. Settings
- **User Profile**: Leg length input (for stride calibration)
- **Units**: Metric vs. Imperial
- **Data Export**: Export runs as CSV or GPX

### App Modules

#### BLE Manager (`BLEManager.swift`)
```swift
class BLEManager: ObservableObject {
    func scanForDevices()
    func connect(peripheral: CBPeripheral)
    func disconnect()
    func discoverServices()
    func subscribeToCharacteristics()
}
```

#### Gait Metrics Model (`GaitMetrics.swift`)
```swift
struct GaitMetrics {
    var strideLength: Float
    var cadence: Int
    var strikeType: StrikeType
    var distance: Float
    var duration: TimeInterval
}
```

#### Run Session Manager (`RunSession.swift`)
```swift
class RunSession: ObservableObject {
    func startRun()
    func pauseRun()
    func stopRun()
    func updateMetrics(from bleData: Data)
    func saveRun()
}
```

## Development Phases

---

## PHASE 1: Hardware Setup & Verification
**Duration**: 3-5 days
**Goal**: Confirm all hardware components work individually

### Tasks
1. **Breadboard Assembly**
   - Wire Arduino Nano 33 BLE Rev2 to breadboard
   - Connect MPU-6050 via I2C (VCC→3.3V, GND→GND, SCL→A5, SDA→A4)
   - Connect MP2636 power module to LiPo battery
   - Wire power module output to Arduino VIN

2. **Component Testing**
   - Run I2C scanner sketch to detect MPU-6050 (should be 0x68)
   - Test MPU-6050: read raw accelerometer and gyroscope values
   - Verify BLE functionality: run simple BLE advertising example
   - Test battery charging circuit
   - Measure idle current draw with multimeter

3. **Calibration**
   - Place device on flat surface
   - Verify accelerometer reads ~1g on Z-axis, ~0g on X/Y
   - Record gyroscope offset values for drift compensation

### Success Criteria
✓ MPU-6050 detected on I2C bus
✓ Raw sensor data readable via serial monitor
✓ BLE advertising visible on iPhone
✓ Battery charges when USB connected
✓ Current draw <100mA during idle

### Deliverables
- Working breadboard prototype
- Documented sensor I2C address and wiring
- Baseline power consumption measurements

---

## PHASE 2: Firmware - IMU Data Acquisition
**Duration**: 5-7 days
**Goal**: Build robust IMU reading and processing pipeline

### Tasks
1. **Library Installation**
   - Install ArduinoBLE library
   - Install MPU6050 library (Adafruit or I2Cdevlib)
   - Install Wire library (built-in)

2. **IMU Module Development** (`imu_sensor.h/cpp`)
   ```cpp
   void initIMU()              // Initialize MPU-6050
   void calibrateIMU()         // Store offset values
   void readIMUData()          // Read accel + gyro at 100Hz
   void updateOrientation()    // Calculate pitch/roll angles
   ```

3. **Sensor Fusion**
   - Implement complementary filter OR simple Kalman filter
   - Combine accelerometer + gyroscope for orientation
   - Calculate pitch angle (critical for strike classification)

4. **Data Validation**
   - Log sensor data to serial at 100Hz
   - Manually move/rotate device, verify orientation updates
   - Simulate foot strikes on desk, observe acceleration peaks

### Success Criteria
✓ IMU reads at stable 100Hz rate
✓ Orientation estimation stable (no excessive drift)
✓ Acceleration peaks detected when tapping device
✓ Data logs cleanly to serial monitor

### Deliverables
- `imu_sensor.h/cpp` module
- Calibration routine that runs on startup
- Serial data logging for debugging

---

## PHASE 3: Firmware - Gait Detection Algorithms
**Duration**: 7-10 days
**Goal**: Implement core gait metrics (foot strike, cadence, stride length)

### Tasks
1. **Foot Strike Detection Module** (`gait_detection.h/cpp`)
   - Implement peak detection on vertical acceleration (Z-axis)
   - Threshold tuning: detect impact >2g acceleration
   - Debounce logic: ignore secondary peaks within 200ms
   - Track stride state machine: SWING → STRIKE → STANCE → SWING

2. **Strike Classification**
   - At each detected strike, read pitch angle
   - Classification logic:
     - Pitch < -15°: HEEL strike
     - Pitch -15° to +5°: MIDFOOT strike
     - Pitch > +5°: FOREFOOT strike
   - Log classification results via serial

3. **Cadence Calculation Module** (`cadence.h/cpp`)
   - Circular buffer storing last 30 foot strike timestamps
   - Calculate: `cadence = (strike_count - 1) / time_span * 60`
   - Update every second
   - Target accuracy: ±3 steps/min (Priority 2 spec)

4. **Stride Length Estimation Module** (`stride_length.h/cpp`)
   - Method: Inverted pendulum model
   - `stride_length = 4 * leg_height * sin(swing_angle / 2)`
   - Integrate gyroscope during swing phase to find max angle
   - Apply correction factors based on testing

5. **Desktop Testing**
   - Tap device on desk at known cadence (use metronome app)
   - Verify cadence calculation accuracy
   - Tilt device to different angles during tap, check strike classification

### Success Criteria
✓ Foot strikes detected reliably (no false positives)
✓ Strike classification >80% accurate in controlled tests
✓ Cadence within ±3 steps of metronome rate
✓ Stride length estimation reasonable (validate later in field)

### Deliverables
- `gait_detection.h/cpp` module
- `cadence.h/cpp` module
- `stride_length.h/cpp` module
- Documented algorithm parameters (thresholds, filters)

---

## PHASE 4: Firmware - Bluetooth Low Energy Communication
**Duration**: 5-7 days
**Goal**: Transmit gait metrics to iOS device in real-time

### Tasks
1. **BLE Service Design** (`ble_comms.h/cpp`)
   - Create custom GATT service (UUID: custom or 0x181A)
   - Define characteristics:
     - Stride Length (float, 4 bytes, notify)
     - Cadence (uint16, 2 bytes, notify)
     - Foot Strike Type (uint8, 1 byte, notify)
     - Battery Level (uint8, 1 byte, notify) - standard UUID 0x2A19
     - IMU Debug Stream (optional, 6 floats, 24 bytes)

2. **BLE Implementation**
   ```cpp
   void initBLE()                    // Setup service + characteristics
   void updateBLEMetrics()           // Send notifications every stride
   void handleBLEConnection()        // Manage connect/disconnect
   void updateBatteryLevel()         // Read voltage, calculate %
   ```

3. **Data Transmission Strategy**
   - Send stride length + strike type immediately after each foot strike
   - Send cadence update every 1 second (rolling average)
   - Send battery level every 30 seconds
   - Keep connection interval 15-30ms for responsiveness

4. **Power Management Module** (`power_mgmt.h/cpp`)
   - Monitor battery voltage via analog pin + voltage divider
   - Calculate battery percentage (3.0V = 0%, 4.2V = 100%)
   - Implement idle detection (no motion for 30 seconds)
   - Enter low-power mode when idle, wake on motion interrupt

5. **Testing with nRF Connect App**
   - Use "nRF Connect" iOS app to scan for device
   - Verify all characteristics appear correctly
   - Subscribe to notifications
   - Simulate foot strikes, watch values update

### Success Criteria
✓ Device advertises as "GaitTracker"
✓ All BLE characteristics readable/subscribable
✓ Notifications sent reliably on each foot strike
✓ Connection stable for 10+ minutes
✓ Battery percentage accurate within ±10%

### Deliverables
- `ble_comms.h/cpp` module
- `power_mgmt.h/cpp` module
- Complete Arduino firmware (`gait_tracker.ino`)
- Battery life estimate (measured current × 700mAh)

---

## PHASE 5: iOS App - BLE Connection & Basic UI
**Duration**: 7-10 days
**Goal**: Create iOS app that connects to device and displays live data

### Tasks
1. **Project Setup**
   - Create new SwiftUI project in Xcode
   - Add CoreBluetooth framework
   - Request Bluetooth permissions in Info.plist
   - Set minimum iOS version to 15.0

2. **BLE Manager** (`BLEManager.swift`)
   ```swift
   class BLEManager: NSObject, ObservableObject, CBCentralManagerDelegate, CBPeripheralDelegate {
       func scanForDevices()
       func connect(peripheral: CBPeripheral)
       func discoverServices()
       func subscribeToCharacteristics()
       func parseCharacteristicData(data: Data)
   }
   ```

3. **Data Models** (`GaitMetrics.swift`)
   ```swift
   struct GaitMetrics {
       var strideLength: Float = 0.0      // meters
       var cadence: Int = 0               // steps/min
       var strikeType: StrikeType = .mid  // heel/mid/forefoot
       var batteryLevel: Int = 100        // percentage
   }

   enum StrikeType: UInt8 {
       case heel = 0
       case mid = 1
       case forefoot = 2
   }
   ```

4. **Connection View** (`ConnectionView.swift`)
   - "Scan for Device" button
   - List of discovered BLE devices
   - Connection status indicator
   - Auto-connect if previously paired

5. **Dashboard View** (`DashboardView.swift`)
   - Large numeric displays for:
     - Cadence (steps/min) - primary metric
     - Stride Length (meters or feet)
     - Distance (cumulative)
     - Duration (timer)
   - Color-coded foot strike indicator:
     - Red circle = Heel strike
     - Yellow circle = Midfoot strike
     - Green circle = Forefoot strike
   - Battery icon in top corner

6. **Testing**
   - Connect app to device
   - Tap device on desk, verify metrics update
   - Check data parsing accuracy
   - Test disconnect/reconnect behavior

### Success Criteria
✓ App scans and finds "GaitTracker" device
✓ Connection established within 10 seconds
✓ Real-time metrics display on screen
✓ No crashes or freezes during normal use
✓ Handles disconnect gracefully

### Deliverables
- Functional iOS app with BLE connection
- Real-time dashboard displaying all metrics
- Clean, readable UI suitable for running

---

## PHASE 6: 3D Enclosure Design & Manufacturing
**Duration**: 5-7 days
**Goal**: Design and print protective enclosure meeting size/durability specs

### Tasks
1. **CAD Design in Autodesk Inventor**
   - Create new part: `GaitTracker_Enclosure.ipt`
   - Set maximum dimensions: 50mm (L) × 40mm (W) × 20mm (H)
   - Design bottom shell:
     - Battery compartment with retention clips
     - Mounting posts for Arduino Nano (4x M2 threaded inserts or snap posts)
     - Recessed area for MPU-6050
     - Rubber dampening cavity in floor
     - Strap mounting slots on sides (aligned with foot longitudinal axis)
   - Design top shell:
     - Snap-fit clips (4 corners, 0.2-0.3mm interference fit)
     - USB-C access port for charging
     - Ventilation holes (optional, for heat dissipation)
   - Create assembly file showing fit

2. **Snap-Fit Mechanics**
   - Design cantilever snap hooks
   - Calculate deflection: ensure PLA can flex without breaking
   - Add chamfers for easy assembly

3. **Rubber Insert Design**
   - Model cavity for 2-3mm thick rubber pad
   - Ensures components don't rattle during high-G impacts
   - Acts as vibration damping

4. **3D Printing**
   - Export STL files (`case_top.stl`, `case_bottom.stl`)
   - Print settings:
     - Material: PLA
     - Layer height: 0.2mm
     - Infill: 20-30%
     - Supports: Yes (for overhangs)
   - Estimated print time: 2-3 hours
   - Estimated material: ~20g PLA

5. **Post-Processing**
   - Remove supports
   - Test fit with components
   - Sand snap-fit clips if too tight
   - Cut rubber dampening pad to size

6. **Assembly Test**
   - Place components in enclosure
   - Verify no interference
   - Check USB-C port alignment
   - Test snap-fit closure (should click securely)

### Success Criteria
✓ Enclosure dimensions ≤ 50×40×20mm (Priority 3)
✓ All components fit without forcing
✓ Snap-fit holds securely, opens without breaking
✓ USB-C accessible for charging
✓ Rubber dampening reduces vibration transmission

### Deliverables
- Inventor CAD files (.ipt, .iam)
- STL files for 3D printing
- 3D printed enclosure (top + bottom)
- Rubber dampening inserts
- Assembly photos/documentation

---

## PHASE 7: System Integration & Bench Testing
**Duration**: 3-5 days
**Goal**: Assemble complete device and validate on workbench

### Tasks
1. **Final Assembly**
   - Solder connections if using breadboard (or use PCB if available)
   - Mount Arduino Nano in enclosure bottom
   - Secure MPU-6050 with adhesive or mount
   - Place rubber dampening under components
   - Route wiring neatly
   - Insert LiPo battery
   - Close enclosure (snap-fit top)

2. **Strap Mounting**
   - Thread elastic straps through mounting slots
   - Adjust length for shoe fit
   - Test attachment to running shoe

3. **Bench Testing**
   - Power on device, verify BLE advertising
   - Connect iOS app
   - Hold device and simulate running motion by hand
   - Verify metrics update in app
   - Test battery life: run continuously for 3+ hours (Priority 5)
   - Measure actual runtime vs. target

4. **Drop Test** (durability check)
   - Drop device from 1 meter onto carpet
   - Verify no component damage
   - Check enclosure integrity
   - Re-test sensor readings

### Success Criteria
✓ Device fits in enclosure without rattling
✓ Strap mounting secure on shoe
✓ Battery lasts ≥3 hours continuous use
✓ Survives drop test without failure
✓ All sensors still functional after assembly

### Deliverables
- Fully assembled device in enclosure
- Mounted on shoe with straps
- Battery life test results documented

---

## PHASE 8: Field Testing & Validation
**Duration**: 7-10 days
**Goal**: Validate device accuracy and reliability in real-world running

### Tasks
1. **Treadmill Testing** (controlled environment)
   - Mount device on right shoe
   - Set treadmill to known pace (e.g., 8 min/mile)
   - Run for 10 minutes
   - Record metrics from app
   - Compare to treadmill display:
     - Distance (calculate from stride length × steps)
     - Cadence (if treadmill shows steps/min)
   - Repeat at 3 different paces: slow, moderate, fast

2. **Track Testing** (outdoor validation)
   - Run on 400m track (known distance)
   - Complete 4 laps (1600m total)
   - Record step count and total distance from app
   - Calculate actual stride length: 1600m / total_steps
   - Compare to app's stride length estimate
   - Target accuracy: ±5% error

3. **Cadence Validation**
   - Video record foot strikes during run (slow motion)
   - Manually count steps for 60 seconds
   - Compare to app's cadence reading
   - Target accuracy: ±3 steps/min (Priority 2 spec)

4. **Strike Pattern Validation**
   - Record slow-motion video of foot strikes from side angle
   - Visually assess heel/mid/forefoot strike
   - Compare to app's classification
   - Target accuracy: >80% agreement over 100 strikes

5. **Durability Testing**
   - Run in various conditions:
     - Morning run (cooler temperature)
     - Afternoon run (warmer temperature)
     - Light rain or dewy grass (moisture test)
   - Check for device failures
   - Verify temperature range: 35-100°F (Priority 6)

6. **Battery Life Validation**
   - Full charge device
   - Run continuously until battery depletes
   - Measure actual runtime
   - Target: ≥3 hours (Priority 5)

7. **Data Collection & Analysis**
   - Collect data from 10+ runs
   - Calculate average errors:
     - Cadence error (steps/min)
     - Stride length error (%)
     - Strike classification accuracy (%)
   - Document failure modes (if any)

### Success Criteria
✓ Cadence within ±3 steps/min (Priority 2) ✓
✓ Stride length within ±5% of actual
✓ Strike classification >80% accurate
✓ Battery lasts 3+ hours (Priority 5) ✓
✓ No failures in temperature range 35-100°F (Priority 6) ✓
✓ Device comfortable, doesn't affect gait

### Deliverables
- Field test report with accuracy metrics
- Video footage of validation runs
- Spreadsheet of collected data vs. ground truth
- Identified issues/improvements needed

---

## PHASE 9: Algorithm Tuning & App Polish
**Duration**: 5-7 days
**Goal**: Refine algorithms based on field data, improve app UX

### Tasks
1. **Algorithm Refinement**
   - Adjust strike detection threshold based on false positive rate
   - Tune stride length model coefficients for better accuracy
   - Implement adaptive thresholds (learn from first few strides)
   - Add filtering to smooth cadence display (moving average)

2. **App Feature Additions**
   - Run History view (`HistoryView.swift`)
     - List of past runs with date, distance, duration
     - Tap to view detailed metrics
   - Settings view (`SettingsView.swift`)
     - Input leg length for stride calibration
     - Toggle units (metric/imperial)
     - Clear run history button
   - Run Session Management (`RunSession.swift`)
     - Start/pause/stop buttons
     - Save completed runs to Core Data
     - Calculate summary statistics (avg cadence, total distance, etc.)

3. **Data Visualization**
   - Add line graphs for:
     - Cadence over time
     - Stride length variation
     - Strike pattern distribution (pie chart)
   - Use Swift Charts or third-party library

4. **Data Export**
   - Export run as CSV file
   - Include timestamp, cadence, stride length, strike type per second
   - Share via iOS share sheet

5. **UI/UX Polish**
   - Improve color scheme and typography
   - Add haptic feedback on foot strikes (optional)
   - Display connection status clearly
   - Add low battery warning

### Success Criteria
✓ Algorithms tuned for real-world accuracy
✓ App has complete feature set
✓ Run data persists across app launches
✓ Export functionality works correctly
✓ UI intuitive and visually appealing

### Deliverables
- Refined firmware with tuned parameters
- Complete iOS app with all features
- User-friendly interface tested on iPhone

---

## PHASE 10: Final Documentation & Production Prep
**Duration**: 3-5 days
**Goal**: Document project and prepare for use/demonstration

### Tasks
1. **User Manual**
   - How to charge device
   - How to mount on shoe
   - How to connect app
   - How to start/stop a run
   - How to interpret metrics
   - Troubleshooting common issues

2. **Technical Documentation**
   - Hardware BOM with part numbers
   - Wiring diagram (Fritzing or hand-drawn)
   - Firmware architecture overview
   - BLE service/characteristic UUIDs
   - Calibration procedure
   - Algorithm descriptions

3. **Code Cleanup**
   - Add comments to complex sections
   - Remove debug print statements
   - Organize files into logical structure
   - Add README.md to code repositories

4. **Optional: Waterproofing**
   - Apply conformal coating to PCB
   - Seal enclosure seams with silicone
   - Test IPX3 water resistance (light spray)

5. **Final Testing Checklist**
   - ✓ All 6 design specifications met
   - ✓ BOM < $60
   - ✓ Cadence accuracy ±3 steps
   - ✓ Size ≤ 50×40×20mm
   - ✓ 100 Hz sampling rate
   - ✓ 3+ hour battery life
   - ✓ Temperature/moisture durability

6. **Demonstration Preparation**
   - Create demo video showing device in use
   - Prepare presentation slides if needed
   - Practice explaining technical approach

### Success Criteria
✓ Complete documentation for replication
✓ Device ready for daily use
✓ All specifications validated and met
✓ Polished presentation materials

### Deliverables
- User manual (PDF)
- Technical documentation (PDF or Markdown)
- Clean, commented code repositories
- Demo video or presentation
- Final project report

---

## Summary Timeline

| Phase | Duration | Focus Area |
|---|---|---|
| 1 | 3-5 days | Hardware setup |
| 2 | 5-7 days | IMU data acquisition |
| 3 | 7-10 days | Gait algorithms |
| 4 | 5-7 days | Bluetooth communication |
| 5 | 7-10 days | iOS app development |
| 6 | 5-7 days | Enclosure design |
| 7 | 3-5 days | Integration |
| 8 | 7-10 days | Field testing |
| 9 | 5-7 days | Refinement |
| 10 | 3-5 days | Documentation |

**Total Estimated Time**: 50-72 days (7-10 weeks working part-time)

## Critical Files to Create

### Arduino Firmware
```
gait_tracker/
├── gait_tracker.ino          # Main sketch
├── imu_sensor.h/.cpp          # IMU interface
├── gait_detection.h/.cpp      # Strike detection & classification
├── stride_length.h/.cpp       # Stride estimation
├── cadence.h/.cpp             # Cadence calculation
├── ble_comms.h/.cpp           # BLE service
├── power_mgmt.h/.cpp          # Power management
└── config.h                   # Configuration constants
```

### iOS App
```
GaitTracker/
├── GaitTrackerApp.swift       # App entry point
├── Views/
│   ├── ConnectionView.swift   # BLE scanning/connection
│   ├── DashboardView.swift    # Real-time metrics
│   ├── HistoryView.swift      # Past runs
│   └── SettingsView.swift     # User settings
├── Models/
│   ├── GaitMetrics.swift      # Data models
│   └── RunSession.swift       # Run management
├── Managers/
│   ├── BLEManager.swift       # CoreBluetooth wrapper
│   └── DataManager.swift      # Persistence
└── Resources/
    └── Info.plist             # BLE permissions
```

### 3D Printing (Autodesk Inventor)
```
enclosure/
├── GaitTracker_Enclosure.ipt  # Inventor part file
├── case_top.stl               # Top shell (snap-fit lid)
├── case_bottom.stl            # Bottom shell with battery compartment
├── rubber_insert.stl          # Shock dampening insert (optional)
└── assembly.iam               # Assembly file showing fit
```

**Design Requirements**:
- Maximum outer dimensions: 50mm × 40mm × 20mm
- Snap-fit assembly (no screws for weight/cost savings)
- Integrated strap mounting slots aligned with longitudinal foot axis
- Internal compartments prevent component shifting during high-G impacts
- Rubber dampening cavity as shown in slide 16

## Enclosure Design Details (Based on Slide 16)

### Manufacturing & Materials
1. **Chassis Material**: PLA filament (3D printed)
   - High strength-to-weight ratio
   - Rapid prototyping capability
   - Cost-effective for low-volume production
   - Meets size constraints

2. **Shock Absorption**: High-density rubber dampening inserts
   - Mitigates high G-forces from running impacts (2.5-3.5× body weight)
   - Acts as mechanical low-pass filter
   - Protects MPU-6050 and Arduino from high-frequency vibrations
   - Critical for data integrity during foot strikes

3. **Design Features**:
   - **Snap-Fit Assembly**: Two-part construction for easy battery/component access
   - **Integrated Mounting Points**: Slots for elastic strap system
   - **Sensor Alignment**: Ensures MPU-6050 aligns with foot's longitudinal axis
   - **Internal Layout**: Optimized volume prevents component shifting during high-speed movement
   - **Dimensions**: ≤50mm × 40mm × 20mm (Priority 3 specification)

### Inventor Modeling Workflow
1. Create parametric model with maximum dimension constraints
2. Design internal mounting features for Arduino Nano + MPU-6050
3. Add battery compartment with retention features
4. Model snap-fit clips with appropriate clearances (0.2-0.3mm)
5. Add strap mounting geometry (slots or loops)
6. Include rubber dampening cavity in floor of enclosure
7. Export to STL for 3D printing

## Verification & Testing

### Hardware Testing
1. **I2C Communication**: Use I2C scanner sketch to verify MPU-6050 address (0x68)
2. **IMU Calibration**: Device on flat surface should read ~1g on Z-axis, ~0g on X/Y
3. **Battery Life**: Measure current draw with multimeter (target <50mA average)
4. **BLE Range**: Test connection stability up to 10 meters

### Firmware Testing
1. **Strike Detection**: Simulate strikes on desk, verify serial output shows detections
2. **Strike Classification**: Tilt device to different angles during strike, verify correct classification
3. **Cadence Accuracy**: Tap device at known frequency (e.g., 180 BPM), verify cadence reading
4. **BLE Data**: Use "nRF Connect" app to verify characteristics update correctly

### Algorithm Validation
1. **Stride Length**:
   - Walk/run known distance (e.g., 100m track)
   - Compare device count vs. actual distance
   - Target accuracy: ±5%

2. **Cadence**:
   - Video record run, manually count steps
   - Compare to device reading
   - Target accuracy: ±2 steps/min

3. **Strike Pattern**:
   - Video record footstrike (slow motion)
   - Compare visual assessment to device classification
   - Target accuracy: >80% agreement

### Field Testing Protocol
1. Mount device securely on right shoe (laces or velcro)
2. Perform 5-minute treadmill run at steady pace
3. Record metrics in app
4. Compare to treadmill display (distance, cadence if available)
5. Repeat with different paces (slow jog, moderate, fast)
6. Test outdoor on track for GPS comparison

### End-to-End Test Scenario
1. Charge device via USB-C
2. Power on device (should auto-advertise BLE)
3. Open iOS app, scan and connect
4. Start run session in app
5. Perform 10-minute run
6. Verify real-time metrics update on screen
7. Stop run, verify data saved to history
8. Export run data as CSV

## Key Technical Challenges & Solutions

### Challenge 1: Stride Length Accuracy
**Problem**: Double integration of acceleration leads to significant drift

**Solutions**:
- Use pendulum model based on swing angle (more reliable)
- Apply zero-velocity updates (ZUPT) when foot is on ground
- Calibrate with user's known stride length over measured distance

### Challenge 2: Strike Classification Reliability
**Problem**: Foot orientation varies between runners, making fixed thresholds unreliable

**Solutions**:
- Implement adaptive thresholds based on first few strides
- Use pattern matching on acceleration waveform shape, not just peak values
- Allow user feedback in app to improve classification over time

### Challenge 3: Battery Life
**Problem**: Continuous IMU sampling at 100Hz drains battery quickly

**Solutions**:
- Use MPU-6050 motion detection interrupt to wake from sleep
- Reduce BLE transmission frequency (send averaged data every 1-2 seconds, not every sample)
- Lower IMU sample rate to 50Hz (still sufficient for gait analysis)
- Implement auto-shutoff after 30 minutes of inactivity

### Challenge 4: Bluetooth Latency
**Problem**: BLE notifications have variable latency, affecting real-time display

**Solutions**:
- Buffer metrics on device, send in batches
- Display moving average in app to smooth out jitter
- Use connection interval of 15-30ms for responsive updates

## Bill of Materials Summary

| Component | Quantity | Purpose | Est. Cost |
|---|---|---|---|
| Arduino Nano 33 BLE Rev2 with headers | 1 | Main microcontroller with BLE | $27.00 |
| MPU-6050 (GY-521) IMU | 1 | Motion sensing | $5.00 |
| MP2636 Power Booster & Charger Module | 1 | Battery management & charging | $8.00 |
| 3.7V 700mAh LiPo Battery | 1 | Power source | $8.00 |
| PLA Filament for enclosure | ~20g | Housing | $0.40 |
| High-density rubber dampening | Small pieces | Shock absorption | $2.00 |
| Elastic straps | 2 | Shoe mounting | $3.00 |
| USB-C Cable | 1 | Charging & programming | $3.00 |
| Breadboard + Wires | 1 set | Prototyping | $5.00 |

**Total Estimated BOM**: ~$56.40 (✓ Meets <$60 requirement)

**Note**: ESP32 and HC-05 Bluetooth module NOT used (incompatible with iOS/redundant)

## Success Criteria

The device will be considered successful if it meets ALL design specifications:

### Must-Meet Requirements (from slide 11)
1. **Priority 1 - Cost**: Total BOM < $60.00 ✓ (Currently $56.40)
2. **Priority 2 - Functionality**: Cadence measured within ±3 step margin of error
3. **Priority 3 - Portability**: Enclosure ≤ 50mm × 40mm × 20mm
4. **Priority 4 - Data Rate**: Minimum 100 Hz sampling rate maintained
5. **Priority 5 - Battery Life**: ≥3 hours continuous operation on single charge
6. **Priority 6 - Durability**: Withstand 35-100°F and light moisture (IPX3)

### Additional Performance Targets
1. **Stride Length Accuracy**: Within ±5% of actual distance over measured course
2. **Strike Classification**: >80% agreement with slow-motion video analysis
3. **BLE Reliability**: Maintains connection for entire run without dropouts
4. **Form Factor**: Device does not interfere with natural running gait
5. **User Experience**:
   - App connects within 10 seconds of device power-on
   - Real-time metrics update smoothly (no large jumps)
   - Run data saves reliably to phone storage

## Next Steps After Plan Approval

1. Set up Arduino IDE with required libraries
2. Create firmware project structure
3. Write IMU initialization and basic data reading code
4. Test hardware connectivity on breadboard
5. Begin iOS app project in Xcode

---

**Note**: This plan assumes moderate software development experience with Arduino and iOS. The firmware complexity is moderate, while the iOS app is beginner-friendly. Estimated total development time: 4-6 weeks working part-time.

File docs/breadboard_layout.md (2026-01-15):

# Breadboard Layout Guide

Complete wiring diagram and assembly instructions for the Gait Tracker breadboard prototype.

## Components Required

| Component | Quantity | Notes |
|---|---|---|
| Arduino Nano 33 BLE Rev2 | 1 | Main microcontroller |
| MPU-6050 (GY-521 breakout) | 1 | 6-axis IMU sensor |
| MP2636 Power Module | 1 | Battery charger & booster |
| 3.7V 700mAh LiPo Battery | 1 | Power source |
| Full-size breadboard | 1 | 830 tie points recommended |
| Male-to-male jumper wires | ~10 | Various colors recommended |
| Micro-USB cable | 1 | For programming Arduino |

## Visual Layout

```
                    BREADBOARD TOP VIEW
    ============================================================

    (+) Red Power Rail    ─────────────────────────────────── (+)
    (-) Blue Ground Rail  ─────────────────────────────────── (-)

    ============================================================

         MPU-6050 (GY-521)              Arduino Nano 33 BLE Rev2
         ┌──────────┐                   ┌────────────────────┐
         │          │                   │                    │
         │   VCC ●──┼───RED─────────────┼──● 3.3V           │
         │   GND ●──┼───BLACK───────────┼──● GND            │
         │   SCL ●──┼───YELLOW──────────┼──● A5 (SCL)       │
         │   SDA ●──┼───GREEN───────────┼──● A4 (SDA)       │
         │   XDA ●  │                   │                    │
         │   XCL ●  │                   │  ● VIN ────────────┼──ORANGE──┐
         │   AD0 ●  │                   │  ● GND ────────────┼──BROWN───┼──┐
         │   INT ●  │                   │                    │          │  │
         └──────────┘                   └────────────────────┘          │  │
                                                                         │  │
                                        MP2636 Power Module              │  │
                                        ┌──────────────┐                │  │
                                        │ Micro-USB IN │ (for charging) │  │
                                        │  USB-A OUT   │ (5V output)    │  │
                                        │  VOUT   ●────┼────────────────┘  │
                                        │  GND    ●────┼───────────────────┘
                                        │              │
                                        │  BAT+   ●────┼───RED──┐
                                        │  BAT-   ●────┼───BLACK┤
                                        └──────────────┘        │
                                                                │
                                        3.7V LiPo Battery       │
                                        ┌──────────────┐        │
                                        │   700mAh     │        │
                                        │  +  ●────────┼────────┘
                                        │  -  ●────────┼────────┐
                                        └──────────────┘        │
                                                                │
                                    (connects to BAT- above) ───┘
```

## Step-by-Step Assembly

### Step 1: Position Components on Breadboard

**Layout from left to right:**

1. **MPU-6050** - Place in leftmost section (rows 1-8)
2. **Arduino Nano 33 BLE Rev2** - Center section (rows 1-30, straddling center gap)
3. **MP2636 Power Module** - Right section (rows 1-10)
4. **LiPo Battery** - Off-board, connected via wires

**Tip:** Leave space between components for wiring and future debugging.

### Step 2: MPU-6050 to Arduino Connections

#### Connection 1: Power (VCC)
- **From:** MPU-6050 `VCC` pin
- **To:** Arduino Nano `3.3V` pin
- **Wire Color:** RED (recommended)
- **CRITICAL:** Use 3.3V, NOT 5V! The MPU-6050 is not 5V tolerant!

#### Connection 2: Ground (GND)
- **From:** MPU-6050 `GND` pin
- **To:** Arduino Nano `GND` pin
- **Wire Color:** BLACK (recommended)

#### Connection 3: I2C Clock (SCL)
- **From:** MPU-6050 `SCL` pin
- **To:** Arduino Nano `A5` pin (hardware I2C clock)
- **Wire Color:** YELLOW (recommended)

#### Connection 4: I2C Data (SDA)
- **From:** MPU-6050 `SDA` pin
- **To:** Arduino Nano `A4` pin (hardware I2C data)
- **Wire Color:** GREEN (recommended)

**Leave unconnected:**
- `XDA` - Auxiliary data (not used)
- `XCL` - Auxiliary clock (not used)
- `AD0` - I2C address select (leave floating for 0x68)
- `INT` - Interrupt pin (not used in Phase 1, may use later for motion wake)

### Step 3: MP2636 to Arduino Connections

#### Connection 5: 5V Power Output
- **From:** MP2636 `VOUT` pin
- **To:** Arduino Nano `VIN` pin
- **Wire Color:** ORANGE (recommended)
- **Note:** This powers the Arduino from the battery

#### Connection 6: Ground
- **From:** MP2636 `GND` pin
- **To:** Arduino Nano `GND` pin (same ground as MPU-6050)
- **Wire Color:** BROWN (recommended)

### Step 4: Battery to MP2636 Connections

#### Connection 7: Battery Positive
- **From:** LiPo Battery RED wire (+)
- **To:** MP2636 `BAT+` pin
- **IMPORTANT:** Double-check polarity! Reversed polarity can damage battery or module!

#### Connection 8: Battery Negative
- **From:** LiPo Battery BLACK wire (-)
- **To:** MP2636 `BAT-` pin

### Step 5: USB Connection for Charging

- **Plug Micro-USB cable into MP2636 module** (not the Arduino)
- **Connect to USB power adapter or computer** to charge battery
- **Note:** The USB-A port is a 5V OUTPUT (alternative to VOUT pin), not for charging
- **LED indicator on MP2636** will show charging status:
  - Red = Charging
  - Green = Fully charged

## Wiring Summary Table

| Connection | From | To | Wire Color | Notes |
|---|---|-----|---|---|
| 1 | MPU-6050 VCC | Arduino 3.3V | RED | Must be 3.3V! |
| 2 | MPU-6050 GND | Arduino GND | BLACK | Common ground |
| 3 | MPU-6050 SCL | Arduino A5 | YELLOW | I2C clock |
| 4 | MPU-6050 SDA | Arduino A4 | GREEN | I2C data |
| 5 | MP2636 VOUT | Arduino VIN | ORANGE | Powers Arduino |
| 6 | MP2636 GND | Arduino GND | BROWN | Common ground |
| 7 | LiPo + (red) | MP2636 BAT+ | RED | Check polarity! |
| 8 | LiPo - (black) | MP2636 BAT- | BLACK | Check polarity! |

## Power Flow Diagram

```
┌─────────────┐
│  LiPo 3.7V  │
│   700mAh    │
└──────┬──────┘
       │
       ▼
┌─────────────┐       USB-C (charging)
│   MP2636    │◄──────────────────
│  Booster +  │
│   Charger   │
└──────┬──────┘
       │ 5V regulated
       ▼
┌─────────────┐
│  Arduino    │
│  Nano 33    │ 3.3V out
│  BLE Rev2   ├──────┐
└─────────────┘      │
                     ▼
              ┌─────────────┐
              │  MPU-6050   │
              │   IMU       │
              └─────────────┘
```

## Important Safety Notes

### CRITICAL WARNINGS

1. **MPU-6050 VOLTAGE:**
   - MUST use 3.3V, NOT 5V
   - The MPU-6050 is not 5V tolerant
   - Using 5V will permanently damage the sensor

2. **BATTERY POLARITY:**
   - Always double-check red (+) and black (-) connections
   - Reversed polarity can cause fire or explosion
   - If unsure, use a multimeter to verify

3. **BATTERY HANDLING:**
   - Never short-circuit the battery
   - Never puncture or damage the battery
   - Keep away from metal objects
   - Store in fireproof container when not in use

4. **CHARGING:**
   - Only charge with MP2636 module or proper LiPo charger
   - Never leave charging unattended
   - Charge in fireproof area
   - Disconnect if battery gets hot

## Testing Checklist

After assembly, verify each step:

###Visual Inspection
- [ ] All wires seated firmly in breadboard holes
- [ ] No loose connections
- [ ] MPU-6050 connected to 3.3V (not 5V)
- [ ] Battery polarity correct (red to BAT+, black to BAT-)
- [ ] No wires crossed or touching

###Power-On Test (without USB programming cable)
- [ ] Connect battery to MP2636
- [ ] Arduino power LED should light up
- [ ] MPU-6050 power LED should light up (if equipped)
- [ ] No smoke, burning smell, or excessive heat

###I2C Communication Test
- [ ] Connect Arduino to computer via Micro-USB
- [ ] Upload I2C scanner sketch
- [ ] Open Serial Monitor (115200 baud)
- [ ] Verify MPU-6050 detected at address 0x68

Expected I2C scanner output:
```
I2C Scanner
Scanning...
I2C device found at address 0x68  !
done
```

###IMU Data Test
- [ ] Upload basic MPU-6050 test sketch
- [ ] Verify accelerometer readings (~1g on Z-axis when flat)
- [ ] Move device and observe values change
- [ ] Gyroscope should read near 0 when stationary

## Troubleshooting

### MPU-6050 Not Detected (no device at 0x68)

**Check:**
1. VCC connected to 3.3V (not 5V)?
2. GND connected properly?
3. SDA connected to A4?
4. SCL connected to A5?
5. All wires firmly inserted?

**Try:**
- Re-seat all MPU-6050 connections
- Swap jumper wires (could be faulty wire)
- Try address 0x69 (some modules have AD0 pulled high)

### Arduino Not Powering On

**Check:**
1. Battery charged? (use multimeter: should read ~3.7-4.2V)
2. MP2636 VOUT connected to Arduino VIN?
3. Common ground between MP2636 and Arduino?
4. Battery polarity correct?

**Try:**
- Charge battery via Micro-USB on MP2636
- Test with Arduino connected to computer USB (bypasses battery)
- Use multimeter to verify 5V on MP2636 VOUT or USB-A output

### Accelerometer Readings Wrong

**Expected when flat on table:**
- X-axis: ~0 g
- Y-axis: ~0 g
- Z-axis: ~1 g (9.8 m/s² or ~1g)

**If readings are off:**
- MPU-6050 may need calibration
- Check if sensor is flat and stable
- Verify 3.3V power supply is stable

## Next Steps After Successful Assembly

Once breadboard is working:

1. **Upload gait_tracker firmware** ([Getting Started Guide](../GETTING_STARTED.md))
2. **Test BLE advertising** (nRF Connect app)
3. **Simulate foot strikes** (tap device on desk)
4. **Proceed to Phase 2** (IMU data acquisition)

## Photos Reference (to be added)

Take photos of your breadboard from multiple angles for reference:
- [ ] Top view showing all components
- [ ] Close-up of MPU-6050 connections
- [ ] Close-up of power connections
- [ ] Label photo with wire colors

## Advanced: Optional Connections for Future Phases

### Battery Voltage Monitoring (Phase 4)
Add voltage divider to measure battery level:

```
Battery + ────┬────── MP2636 BAT+
              │
           10kΩ resistor
              │
              ├────────── Arduino A0 (analog input)
              │
           10kΩ resistor
              │
Battery - ────┴────── MP2636 BAT-
```

### MPU-6050 Interrupt (Phase 7)
For motion detection wake-up:

```
MPU-6050 INT ─────── Arduino D2 (interrupt pin)
```

These are not needed for Phase 1 testing.

---

**Assembly time:** ~15-20 minutes
**Difficulty:** Beginner-friendly (no soldering required)
**Cost:** ~$56 (see Bill of Materials in main README)

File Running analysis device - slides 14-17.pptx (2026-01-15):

## Validation of problem

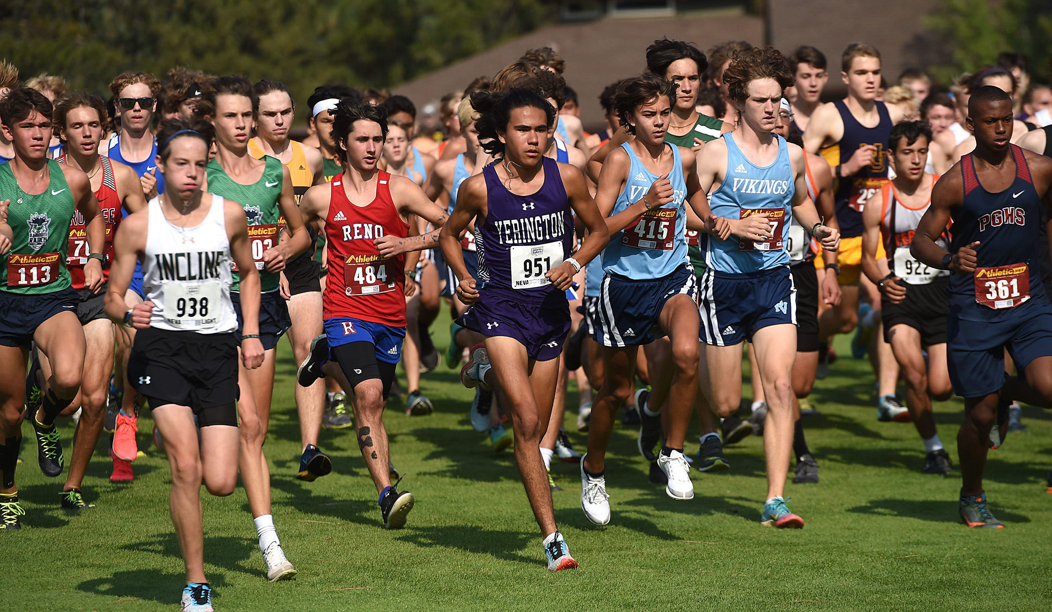
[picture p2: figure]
Stevens the fastest, but who are the other top cross country runners in the North?

- Consumers, Users, and Interviews: Among high school cross-country runners it was indicated that 60% were unaware of their current running cadence, yet 75% of them expressed concern about past or potential injury. The consensus among users is that professional gait analysis is too expensive and hard to access to be a practical training tool.
- Scholarly Articles: Research published in the Journal of Orthopaedic & Sports Physical Therapy confirms that increasing a runner's cadence by 5-10% can significantly reduce loading rates at the knee and hip, validating the need for simple cadence feedback.
- Brief Summary of Existing Products and Patents: High-end competitive products offer power metrics but are priced at over $200, confirming the existence of a high-price barrier. Existing patents primarily focus on complex multi-sensor systems, which drives up manufacturing cost.

## Statistics:

- Injury Prevalence (Why the Problem Exists)
  - 79%, The estimated amount of runners who sustained an injury that interferes with running activity during any given year.
  - 50-70%, The range of running injuries that are overuse injuries, which are directly linked to repetitive stress from poor biomechanics.
  - 20 to 40 times, The magnitude of increase in the average runner's injury risk when transitioning from low to high mileage without correcting underlying form flaws.
- Biomechanics and Impact (Why the Solution Works)
  - 170-180 steps per minute, The widely accepted "optimal" cadence range for reducing impact forces.
  - 5-10%, The required increase in a runner's cadence shown to significantly reduce stress on the hip, knee, and ankle joints. Your device provides the data needed for this precise adjustment.
  - 2.5-3.5 times body weight, The typical peak vertical ground reaction force experienced during running. Monitoring and reducing force is the best way to prevent bone stress injuries.
- Cost & Accessibility (Why Our Project is Necessary)
  - $350 to $500, The average cost for a single, professional in-lab gait analysis session.
  - <$60, Our project's estimated bill of materials cost.
  - 4 to 8 weeks, The typical length of time a runner may need physical therapy for a moderate overuse injury.

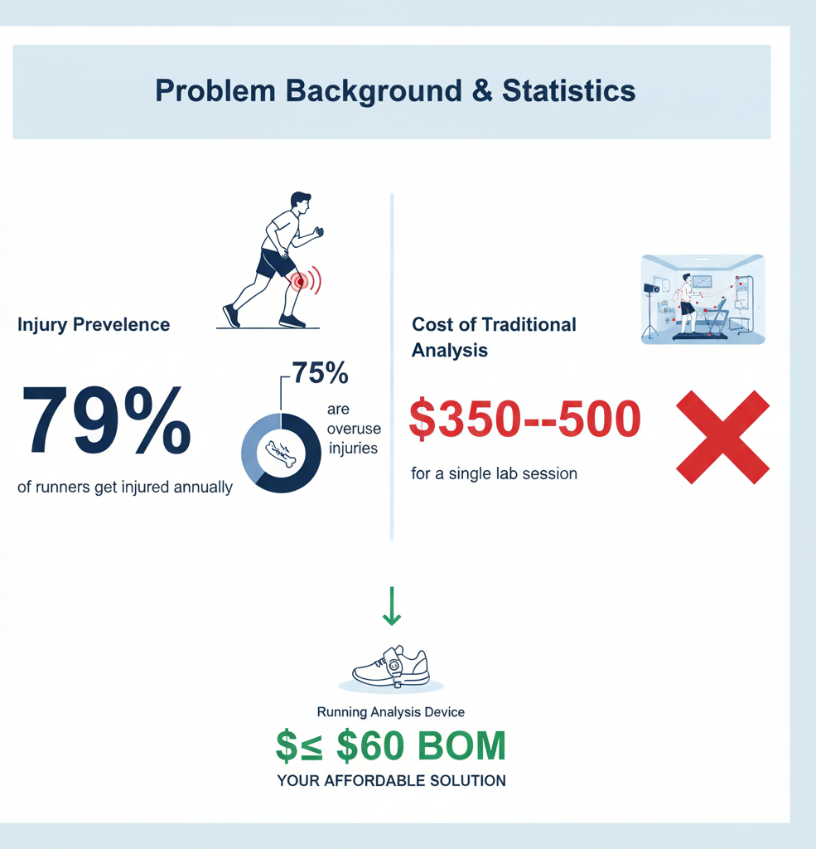
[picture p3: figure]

## Gathering info

We found our information primarily from online research on various topics within our project. Information we gathered from this research included analyzing both developed commercial products and patented technologies that address gait analysis. One of the main things we were looking at was the cost versus data trade off in existing products that work.

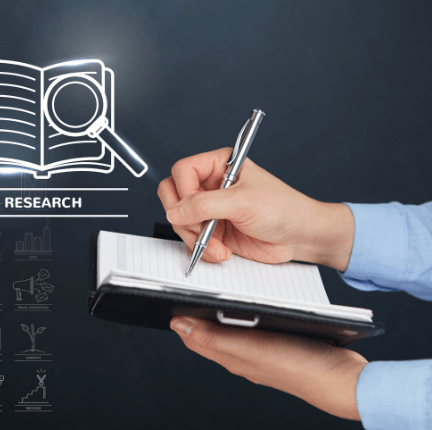
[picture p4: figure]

ThePhoto by PhotoAuthor is licensed under CCYYSA.

ThePhoto by PhotoAuthor is licensed under CCYYSA.

## Similar patents

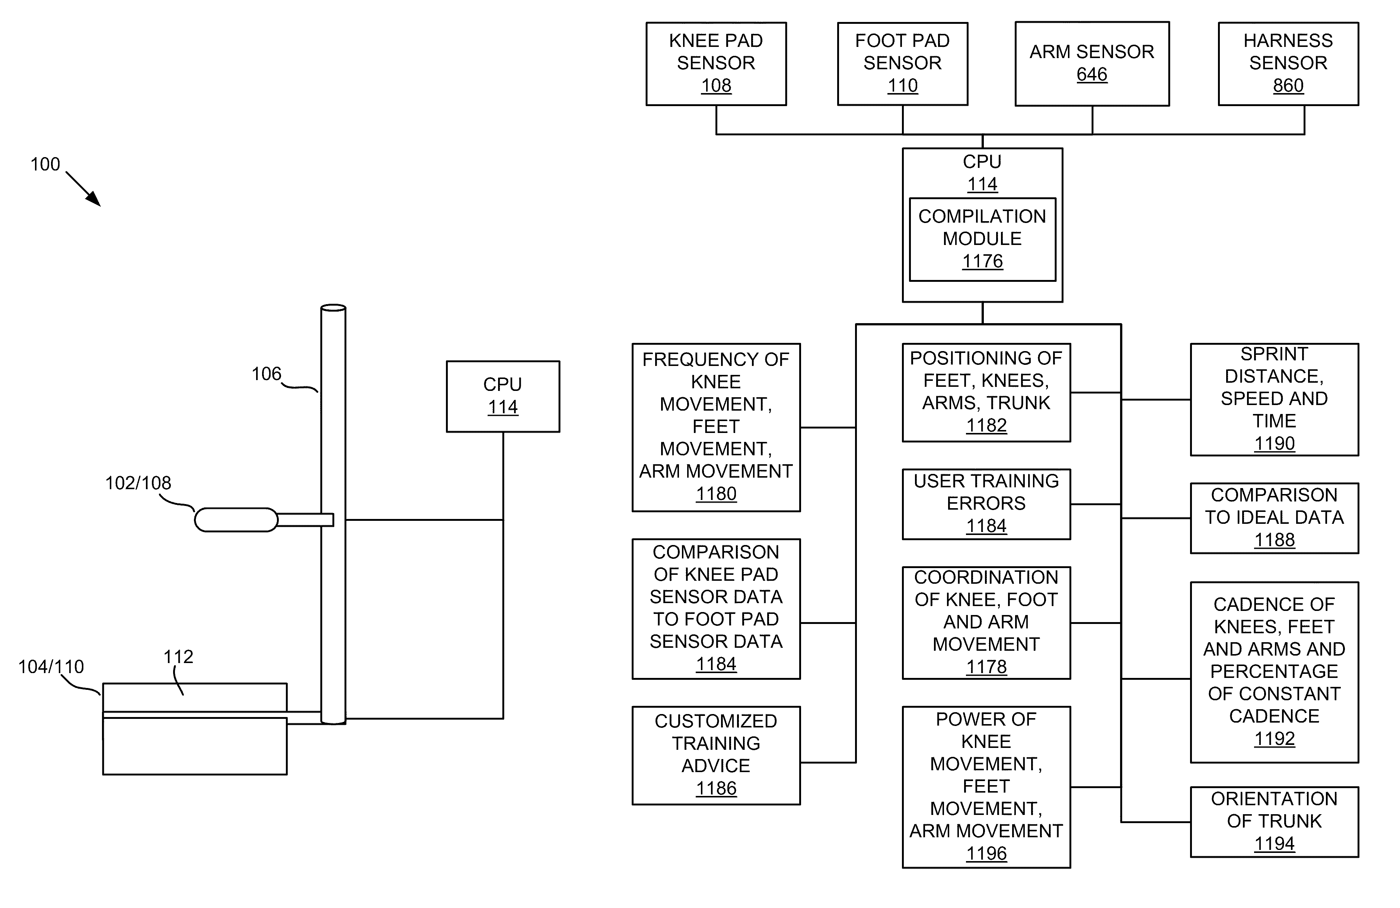
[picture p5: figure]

## Similar Patents

Abstract
  - An apparatus, system, and method are disclosed for accurate measurement, compilation, and presentation of sprinting and running technique data. In one embodiment, the apparatus, system and method includes a knee pad configured to contain a knee pad sensor, a foot pad configured to contain a foot pad sensor and a main trunk that connects the foot pad and the kneepad. The knee pad sensor and the foot pad sensor sense movement near the sensors and contact to the sensors. Data from the sensors is output to a CPU. In one embodiment, the apparatus, system and method include arm sensors. The arm sensors sense arm movement of a user and report arm movement data to the CPU. In a further embodiment, the apparatus may be configured to contain a harness positioned opposite the main trunk.

Date of patent
  - 03/08/2011

Pros
  - Provides detailed feedback
  - Pinpoints mistakes

Patent number
  - US7901325B2

Cons
  - Clunky
  - If the sensors move at all then data become inaccurate

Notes: Summary
This devices goal was to track a persons movement during running or sprinting and return collected data to the user to help them improve.
The device would've done this by returning data collected from sensors in pads that go on the knee and foot and sending that data to a computer to process it and return it to the user

## Similar devices

- RunScribe
  - 2 small compact devices that attaches to the laces of your shoes and tracks cadence and stride length and sends that data to an app that they have so that the user can see the data.
- Price
  - 600$
- Pros
  - Small and compact
  - Measures and returns a bunch of different data
- Cons
  - Expensive
  - Is out of business

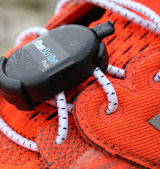
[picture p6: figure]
RunScribe Plus Review - Footpod ...

## Similar devices

- Stryd
  - A compact device that goes on the laces of your shoes and like RunScribe tracks cadence and stride length and sends that data to an app of theirs so that users can see the data
- Price
  - 200$ for their best version (stryd 5.0)
- Pros
  - Instantaneous feedback
  - Highly accurate
- Cons
  - Expensive
  - Uses a measurement system called power which isnt well known and requires a learning curve

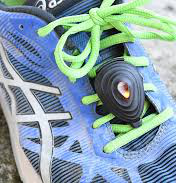
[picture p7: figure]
Stryd announces new running power meter ...

## Primary Stake Holder

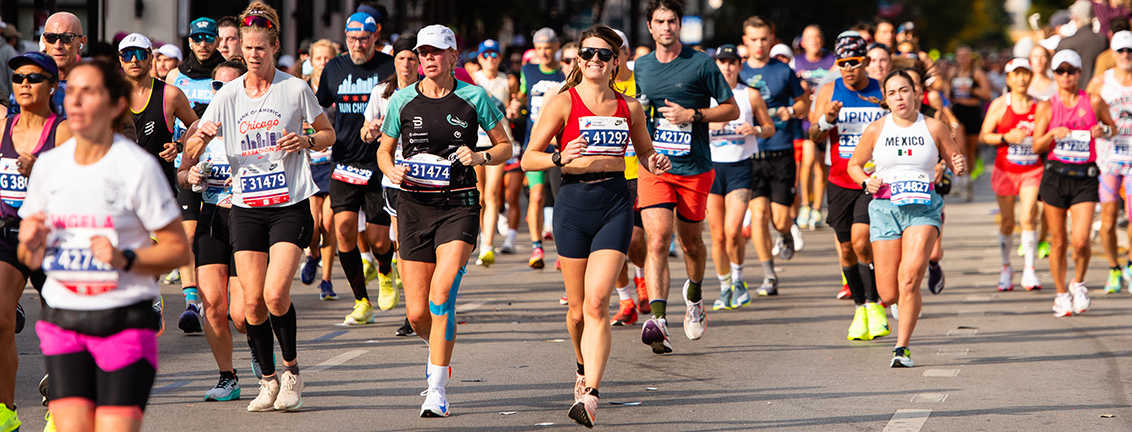
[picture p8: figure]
RUNNER INFORMATION - Bank of America Chicago Marathon

Input on Design Requirements

Users/Buyers Input: We have estimated that cost tolerance would likely be under $75, and the device must be small enough not to interfere with stride or balance.
Manufacturers Input: Component selection was limited to common, off-the-shelf microcontrollers and sensors (Arduino Nano, MPU-6050) to ensure low BOM and ease of assembly.

- Users: Recreational runners and high school athletes
- Buyers: Parents, coaches, or school athletic departments.
- Sellers: E-commerce platforms and/or sporting goods stores.
- Manufacturers: Electronics assemblers.

## Communication Log

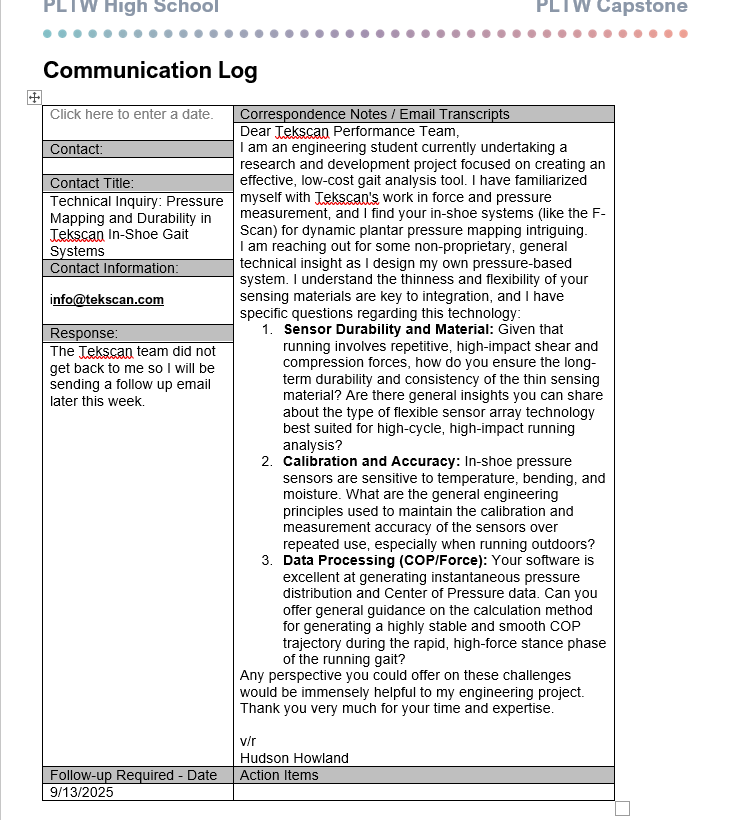
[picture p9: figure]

- I reached out to Tekscan because I like their concept with the shoe insert and the ankle mount.
- Did not receive an email back from their team
- Planning on sending a follow up email next week.

## Determination of Design Specifications

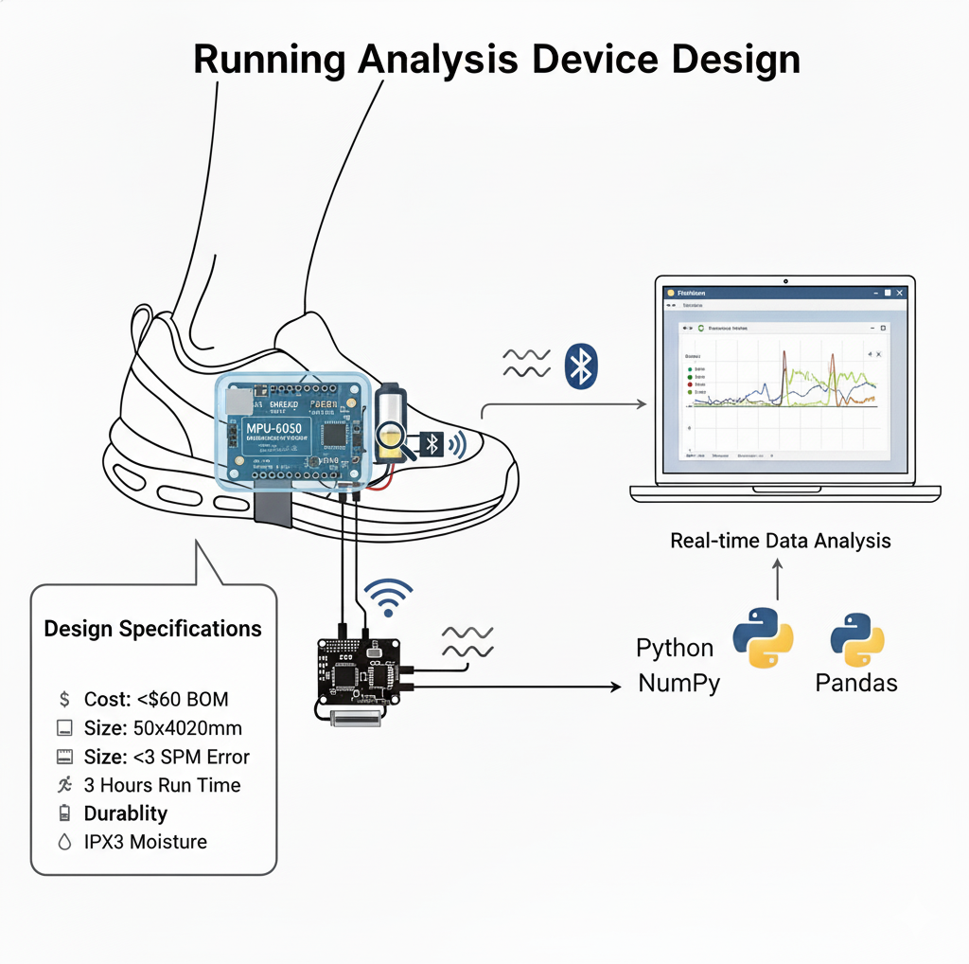
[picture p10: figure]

- Our design specifications have been determined by balancing user focused needs with technical feasibility and cost constraints. The core objective is to achieve high accuracy for high-impact events without the high cost associated with lab equipment. Input from target users and technical research guides our prioritization of functional requirements over non-essential features, ensuring a minimum viable product that solves the core problem.

## Design Specifications

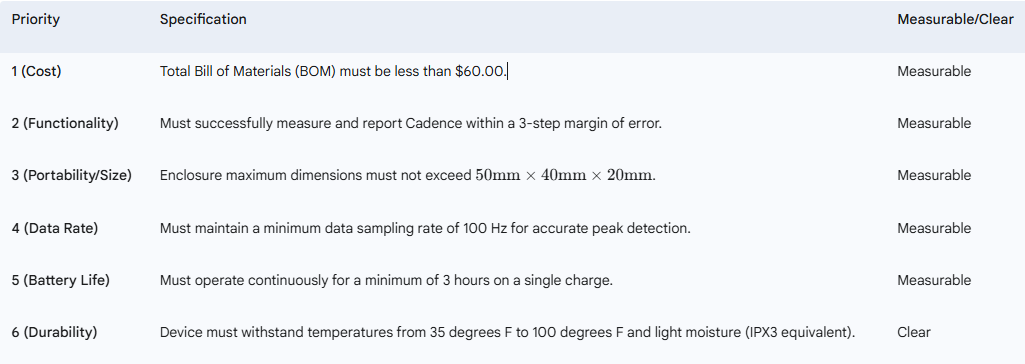
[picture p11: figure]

## Design concepts

Concept 1

Concept 2

Concept 3

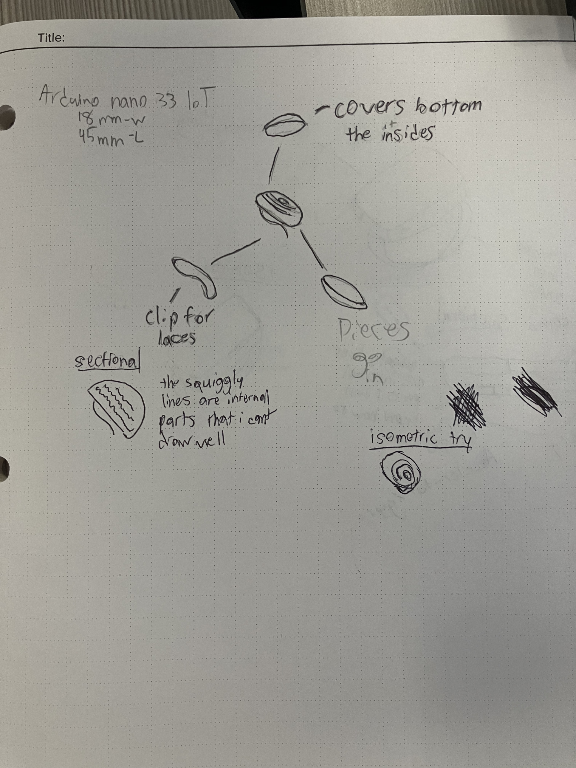
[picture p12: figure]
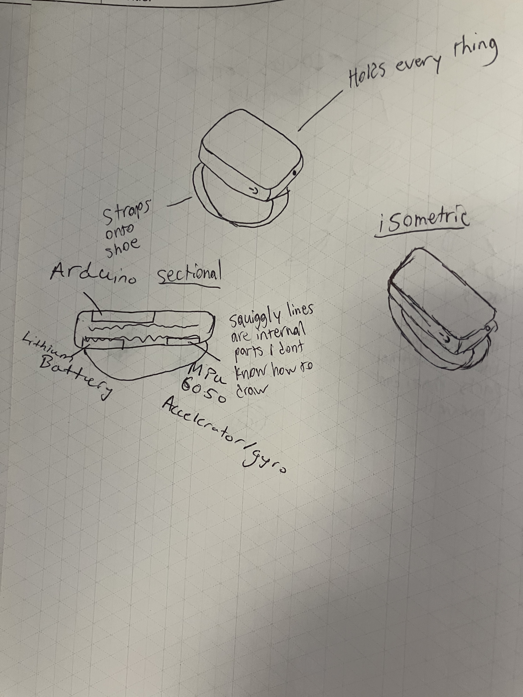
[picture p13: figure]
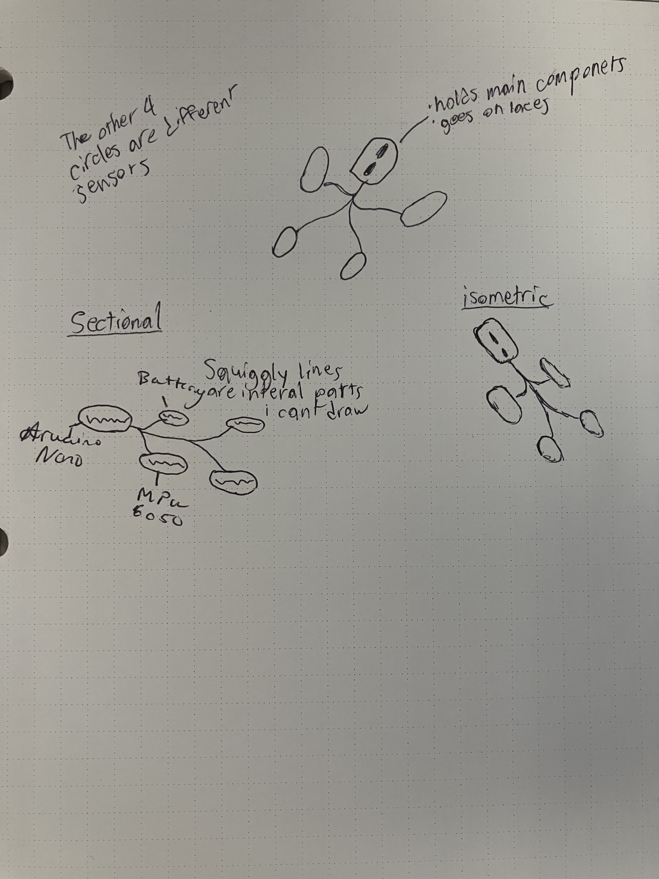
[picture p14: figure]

## Decision matrix

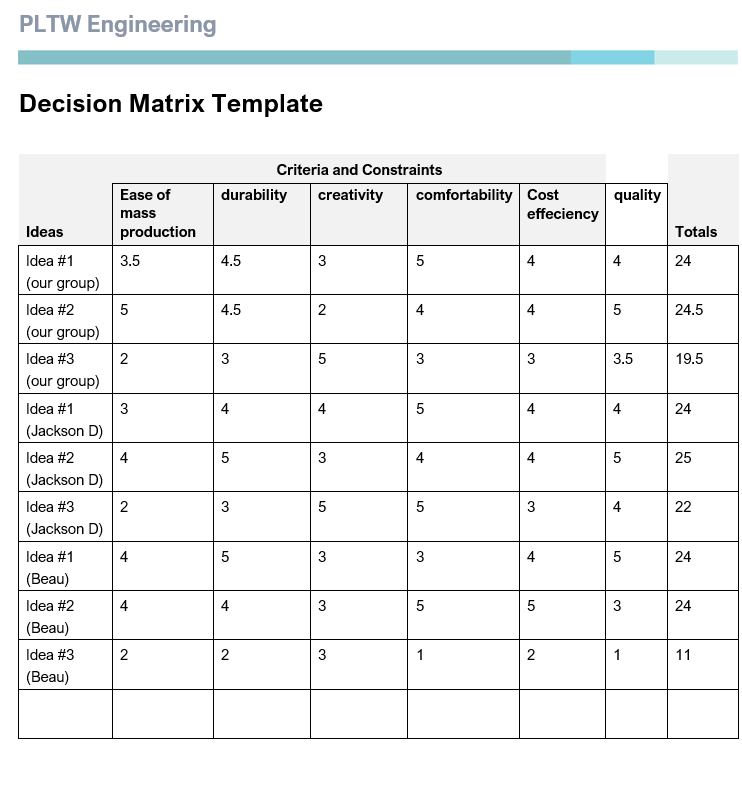
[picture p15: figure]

## Design concepts: Final Design

Concept 2

- This design had the best total score out of each design we tested with the design matrix.
- Although this design is not the most creative, we determined that it is the best option because it is simple, cost effective, and durable.

## Final decision

## Final Prototype

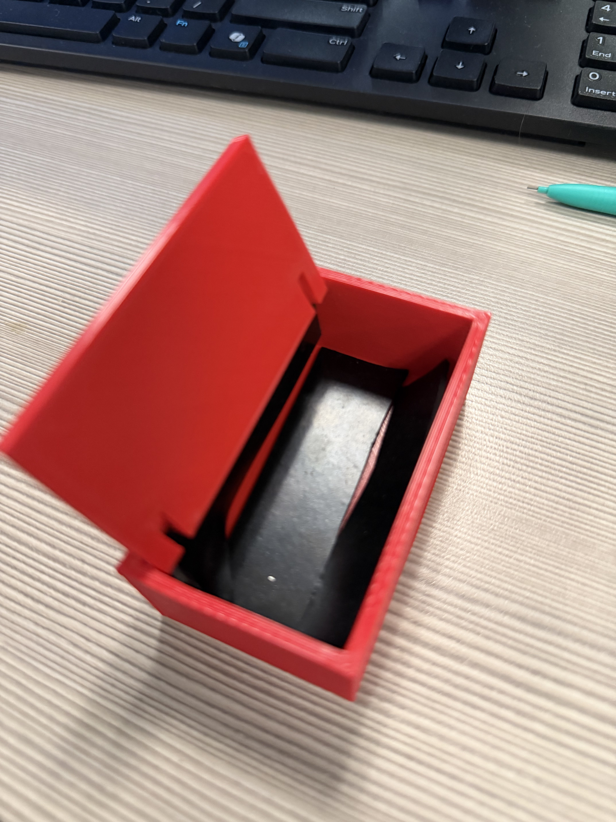
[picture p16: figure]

Design Features
- Snap-Fit Assembly: The box is designed with a two-part construction for easy access to the battery and internal components during the testing phase.
- Integrated Mounting Points: The exterior geometry includes specialized slots to accommodate the elastic strap system, ensuring the sensor remains aligned with the foot's longitudinal axis.
- Internal Layout: The internal volume is optimized to prevent component shifting, which is critical for maintaining data integrity during high-speed movement.

Manufacturing & Materials
- Chassis Material: PLA Filament. We used inventor modeling and 3D printing to create the main enclosure. PLA was selected for its high strength-to-weight ratio and ease of rapid prototyping, ensuring the device meets our Priority constraints.
- Shock Absorption: High-Density Rubber Dampening. To mitigate the high G-forces of running impacts, the internal cavity features rubber inserts. These act as a mechanical low-pass filter, protecting the sensitive MPU-6050 sensor and Arduino from high-frequency vibrations and structural shock.

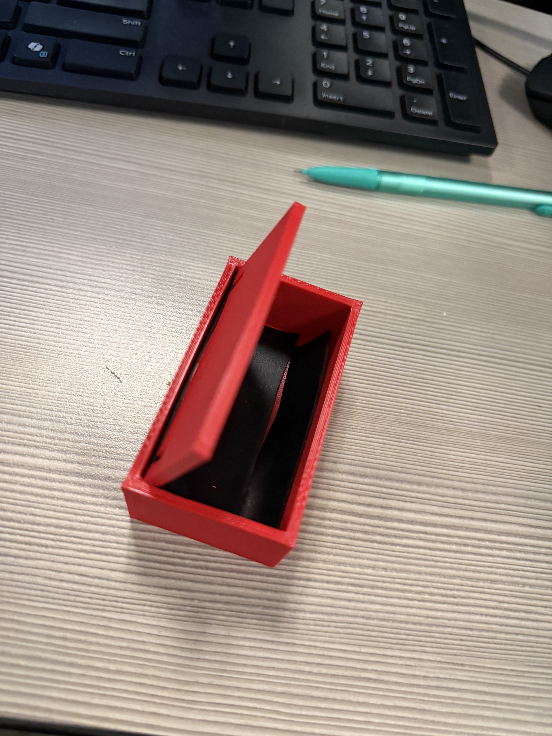
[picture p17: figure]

## References:

- Kakouris, N., Yener, N., & Fong, D. T. P. (2021, September). A systematic review of running-related musculoskeletal injuries in Runners. Journal of sport and health science. https://pmc.ncbi.nlm.nih.gov/articles/PMC8500811/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,stress%20syndrome%20is%20the%20most%20common%20RRMI.
- Are you risking injury by going too far in your long run? here’s what new research says. (n.d.). https://www.runnersworld.com/health-injuries/a65792883/rethink-mileage-increase-running-injuries/
- Mason, R., Pearson, L. T., Barry, G., Young, F., Lennon, O., Godfrey, A., & Stuart, S. (2023, January). Wearables for running gait analysis: A systematic review. Sports medicine (Auckland, N.Z.). https://pmc.ncbi.nlm.nih.gov/articles/PMC9807497/
- Mason, R., Godfrey, A., Barry, G., & Stuart, S. (n.d.). Wearables for running Gait Analysis: A study protocol. PLOS ONE. https://journals.plos.org/plosone/article?id=10.1371%2Fjournal.pone.0291289
- Wearable IMU - gait analysis. RunScribe. (2019, June 9). https://runscribe.com/
- Stryd: Run with power. Stryd (United States). (n.d.). https://www.stryd.com/us/en
- Henderson, J. (2011, March 3). Athletic training device.
- Mason, R., Pearson, L. T., Barry, G., Young, F., Lennon, O., Godfrey, A., & Stuart, S. (2022, October 15). Wearables for running gait analysis: A systematic review - sports medicine. SpringerLink. https://link.springer.com/article/10.1007/s40279-022-01760-6

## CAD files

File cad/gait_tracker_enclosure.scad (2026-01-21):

/*
 * Gait Tracker Enclosure
 *
 * Enclosure for:
 * - Arduino Nano 33 BLE Rev2
 * - MPU-6050 (GY-521 breakout)
 * - MP2636 Power Module (DFRobot DFR0446)
 * - 3.7V 700mAh LiPo Battery
 *
 * To generate STL:
 * 1. Install OpenSCAD (openscad.org)
 * 2. Open this file
 * 3. Press F6 to render
 * 4. File -> Export -> Export as STL
 */

// ============================================================================
// COMPONENT DIMENSIONS (mm)
// ============================================================================

// Arduino Nano 33 BLE Rev2
arduino_length = 45;
arduino_width = 18;
arduino_height = 5;  // PCB thickness + components
arduino_usb_height = 3;
arduino_usb_width = 8;
arduino_usb_depth = 6;

// MPU-6050 GY-521 Breakout
mpu_length = 21;
mpu_width = 16;
mpu_height = 3;

// MP2636 Power Module (DFRobot DFR0446)
mp2636_length = 28;
mp2636_width = 18;
mp2636_height = 4;
mp2636_usb_micro_width = 8;
mp2636_usb_micro_height = 3;
mp2636_usb_a_width = 14;
mp2636_usb_a_height = 7;

// LiPo Battery 700mAh (typical dimensions)
battery_length = 50;
battery_width = 34;
battery_height = 6;

// Enclosure parameters
wall_thickness = 2;
clearance = 1;  // Space around components
mounting_post_diameter = 3;
screw_hole_diameter = 2;
lid_lip = 1.5;

// ============================================================================
// CALCULATED DIMENSIONS
// ============================================================================

internal_length = battery_length + clearance * 2;
internal_width = arduino_width + mp2636_width + mpu_width + clearance * 4;
internal_height = max(arduino_height, mp2636_height, mpu_height, battery_height) + clearance * 2;

box_length = internal_length + wall_thickness * 2;
box_width = internal_width + wall_thickness * 2;
box_height = internal_height + wall_thickness;

// ============================================================================
// MAIN ASSEMBLY
// ============================================================================

// Choose what to render
render_bottom = true;
render_lid = true;
exploded_view = true;
explosion_distance = 30;

if (render_bottom) {
    enclosure_bottom();
}

if (render_lid) {
    translate([0, 0, exploded_view ? box_height + explosion_distance : 0])
        enclosure_lid();
}

// ============================================================================
// ENCLOSURE BOTTOM
// ============================================================================

module enclosure_bottom() {
    difference() {
        // Main box body
        rounded_box(box_length, box_width, box_height, 3);

        // Hollow out interior
        translate([wall_thickness, wall_thickness, wall_thickness])
            rounded_box(internal_length, internal_width, internal_height + 1, 2);

        // Micro-USB access for Arduino (front)
        translate([wall_thickness + clearance + arduino_length/2 - arduino_usb_width/2,
                   -1,
                   wall_thickness + clearance + arduino_height - arduino_usb_height])
            cube([arduino_usb_width, wall_thickness + 2, arduino_usb_height + 1]);

        // Micro-USB access for MP2636 (side)
        translate([-1,
                   wall_thickness + clearance + arduino_width + clearance + mp2636_width/2 - mp2636_usb_micro_width/2,
                   wall_thickness + clearance + mp2636_height - mp2636_usb_micro_height])
            cube([wall_thickness + 2, mp2636_usb_micro_width, mp2636_usb_micro_height + 1]);

        // USB-A access for MP2636 (side)
        translate([-1,
                   wall_thickness + clearance + arduino_width + clearance + mp2636_width/2 - mp2636_usb_a_width/2,
                   wall_thickness + clearance])
            cube([wall_thickness + 2, mp2636_usb_a_width, mp2636_usb_a_height]);

        // Lid screw holes (countersunk)
        corner_screws(countersink=true);
    }

    // Mounting posts for components
    component_mounting_posts();

    // Lid retention lip
    translate([wall_thickness + lid_lip, wall_thickness + lid_lip, box_height - wall_thickness])
        difference() {
            rounded_box(internal_length - lid_lip * 2, internal_width - lid_lip * 2, wall_thickness, 1.5);
            translate([0, 0, -0.5])
                rounded_box(internal_length - lid_lip * 2 - wall_thickness,
                           internal_width - lid_lip * 2 - wall_thickness,
                           wall_thickness + 1, 1);
        }
}

// ============================================================================
// ENCLOSURE LID
// ============================================================================

module enclosure_lid() {
    difference() {
        // Main lid plate
        rounded_box(box_length, box_width, wall_thickness, 3);

        // Screw holes
        corner_screws(countersink=false);

        // Ventilation slots for heat dissipation
        for (i = [0:4]) {
            translate([box_length/2 - 15 + i * 7, box_width/2 - 10, -0.5])
                cube([2, 20, wall_thickness + 1]);
        }
    }
}

// ============================================================================
// COMPONENT MOUNTING POSTS
// ============================================================================

module component_mounting_posts() {
    post_height = internal_height - clearance;

    // Arduino Nano mounting posts (4 corners)
    arduino_x = wall_thickness + clearance;
    arduino_y = wall_thickness + clearance;

    translate([arduino_x + 2, arduino_y + 2, wall_thickness])
        mounting_post(post_height, mounting_post_diameter, screw_hole_diameter);
    translate([arduino_x + arduino_length - 2, arduino_y + 2, wall_thickness])
        mounting_post(post_height, mounting_post_diameter, screw_hole_diameter);
    translate([arduino_x + 2, arduino_y + arduino_width - 2, wall_thickness])
        mounting_post(post_height, mounting_post_diameter, screw_hole_diameter);
    translate([arduino_x + arduino_length - 2, arduino_y + arduino_width - 2, wall_thickness])
        mounting_post(post_height, mounting_post_diameter, screw_hole_diameter);

    // MPU-6050 mounting posts (2 corners)
    mpu_x = wall_thickness + clearance;
    mpu_y = wall_thickness + clearance + arduino_width + clearance * 2;

    translate([mpu_x + 2, mpu_y + 2, wall_thickness])
        mounting_post(post_height, mounting_post_diameter, screw_hole_diameter);
    translate([mpu_x + mpu_length - 2, mpu_y + mpu_width - 2, wall_thickness])
        mounting_post(post_height, mounting_post_diameter, screw_hole_diameter);

    // MP2636 mounting posts (2 corners)
    mp2636_x = wall_thickness + clearance;
    mp2636_y = wall_thickness + clearance + arduino_width + clearance + mpu_width + clearance;

    translate([mp2636_x + 2, mp2636_y + 2, wall_thickness])
        mounting_post(post_height, mounting_post_diameter, screw_hole_diameter);
    translate([mp2636_x + mp2636_length - 2, mp2636_y + mp2636_width - 2, wall_thickness])
        mounting_post(post_height, mounting_post_diameter, screw_hole_diameter);
}

// ============================================================================
// HELPER MODULES
// ============================================================================

module mounting_post(height, diameter, hole_diameter) {
    difference() {
        cylinder(h=height, d=diameter, $fn=20);
        translate([0, 0, -0.5])
            cylinder(h=height + 1, d=hole_diameter, $fn=16);
    }
}

module corner_screws(countersink=false) {
    screw_inset = 4;

    positions = [
        [screw_inset, screw_inset],
        [box_length - screw_inset, screw_inset],
        [screw_inset, box_width - screw_inset],
        [box_length - screw_inset, box_width - screw_inset]
    ];

    for (pos = positions) {
        translate([pos[0], pos[1], -0.5]) {
            cylinder(h=wall_thickness + 1, d=screw_hole_diameter, $fn=16);
            if (countersink) {
                translate([0, 0, wall_thickness - 1])
                    cylinder(h=2, d1=screw_hole_diameter, d2=screw_hole_diameter + 2, $fn=16);
            }
        }
    }
}

module rounded_box(length, width, height, radius) {
    hull() {
        translate([radius, radius, 0])
            cylinder(h=height, r=radius, $fn=30);
        translate([length - radius, radius, 0])
            cylinder(h=height, r=radius, $fn=30);
        translate([radius, width - radius, 0])
            cylinder(h=height, r=radius, $fn=30);
        translate([length - radius, width - radius, 0])
            cylinder(h=height, r=radius, $fn=30);
    }
}

// ============================================================================
// NOTES
// ============================================================================
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

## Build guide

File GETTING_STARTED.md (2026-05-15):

# Getting Started with Gait Tracker

Quick start guide to begin developing your running gait tracker device.

## What You Have Now

**Complete Project Structure**
- Arduino firmware skeleton (all 6 modules)
- iOS app structure and documentation
- Configuration files
- Complete implementation plan

## Next Steps: Phase 1 - Hardware Setup

### What You Need

**Hardware:**
- Arduino Nano 33 BLE Rev2
- MPU-6050 IMU module (GY-521 breakout)
- MP2636 Power Booster & Charger Module
- 3.7V 700mAh LiPo battery
- Breadboard
- Jumper wires
- Micro-USB cable (for programming)

**Software:**
- Arduino IDE (Download from arduino.cc)
- Serial monitor or terminal

### Step-by-Step Instructions

#### 1. Install Arduino IDE
```bash
# Download from: https://www.arduino.cc/en/software
# Install and launch Arduino IDE
```

#### 2. Install Required Libraries
In Arduino IDE:
1. Go to **Tools → Manage Libraries**
2. Search and install:
   - `ArduinoBLE` (by Arduino)
   - `Adafruit MPU6050` (by Adafruit)
   - `Adafruit Unified Sensor` (dependency)

#### 3. Configure Arduino IDE
1. Go to **Tools → Board → Arduino Mbed OS Nano Boards → Arduino Nano 33 BLE**
2. Select correct COM port: **Tools → Port**

#### 4. Assemble Breadboard
Connect components following this wiring:

```
MPU-6050          Arduino Nano 33 BLE Rev2
--------          -----------------------
VCC       →       3.3V
GND       →       GND
SCL       →       A5 (SCL pin)
SDA       →       A4 (SDA pin)

MP2636            Arduino Nano
------            ------------
5V OUT    →       VIN
GND       →       GND

LiPo Battery      MP2636
------------      ------
Red (+)   →       BAT+
Black (-) →       BAT-
```

**Important:** Use 3.3V for MPU-6050, NOT 5V!

#### 5. Test I2C Connection (CRITICAL)
Before proceeding, verify MPU-6050 is detected:

1. Open Arduino IDE
2. Go to **File → Examples → Wire → i2c_scanner**
3. Upload to Arduino Nano
4. Open **Tools → Serial Monitor** (set to 115200 baud)
5. You should see: `I2C device found at address 0x68`

If you don't see 0x68, check your wiring!

#### 6. Prepare Firmware for Upload
The firmware has placeholder code that needs libraries installed:

1. Open `gait_tracker/imu_sensor.cpp`
2. Uncomment the library includes at the top:
   ```cpp
   // TODO: Add MPU6050 library
   #include <Adafruit_MPU6050.h>
   #include <Adafruit_Sensor.h>
   ```

3. Uncomment the initialization code (search for "TODO: Replace")

4. Repeat for `gait_tracker/ble_comms.cpp`:
   ```cpp
   #include <ArduinoBLE.h>
   ```

#### 7. Upload Test Firmware
1. Open `gait_tracker/gait_tracker.ino` in Arduino IDE
2. Click **Verify** (checkmark icon) - should compile without errors
3. Click **Upload** (arrow icon)
4. Open **Serial Monitor** (magnifying glass icon)
5. Set baud rate to **115200**
6. You should see initialization messages

Expected output:
```
=== Gait Tracker Starting ===
Initializing IMU...
MPU6050 Found!
Calibrating IMU...
Calibration complete
Initializing BLE...
BLE service started. Device name: GaitTracker
...
```

#### 8. Verify BLE Advertising
On your iPhone:
1. Download "nRF Connect" app from App Store
2. Open app and tap "SCAN"
3. Look for device named "GaitTracker"
4. If you see it, BLE is working!

#### 9. Test Strike Detection
With device powered and serial monitor open:
1. Pick up the device
2. Tap it firmly on your desk
3. You should see in serial monitor:
   ```
   >>> Foot strike detected <<<
   Strike classified as: MIDFOOT (pitch: 2.3°)
   ```

If you see this, congratulations! Your hardware is working!

## Troubleshooting

### MPU-6050 Not Detected
- **Check wiring** - Especially SDA/SCL pins
- **Check voltage** - Must be 3.3V, not 5V
- **Try different I2C address** - Some modules use 0x69
  - Edit `config.h`: Change `MPU6050_ADDRESS` to `0x69`

### BLE Not Advertising
- **Verify board selection** - Must be "Arduino Nano 33 BLE"
- **Check library installation** - ArduinoBLE must be installed
- **Check serial output** - Look for error messages
- **Reboot device** - Disconnect and reconnect power

### No Serial Output
- **Check baud rate** - Must be 115200
- **Check COM port** - Correct port selected in Tools → Port
- **Try different USB cable** - Some cables are power-only

### Strike Detection Not Working
- **Tap harder** - Needs >2g acceleration
- **Check IMU orientation** - Z-axis should be vertical
- **Adjust threshold** - Edit `config.h`: `STRIKE_THRESHOLD`

## What's Next?

Once Phase 1 is complete:

### Phase 2: IMU Data Acquisition
- Implement sensor fusion algorithm
- Test orientation tracking
- Validate 100Hz sampling rate

### Phase 3: Gait Detection
- Tune strike detection threshold
- Test strike classification accuracy
- Validate cadence calculation

### Phase 4: BLE Communication
- Test data transmission to phone
- Verify characteristic updates
- Measure battery life

Then proceed through Phases 5-10 as outlined in [initial.md](initial.md).

## Getting Help

**Check these files:**
- [README.md](README.md) - Project overview
- [initial.md](initial.md) - Complete implementation plan
- [gait_tracker/README.md](gait_tracker/README.md) - Firmware details

**Common Issues:**
- Most problems are wiring-related - double-check connections
- I2C scanner is your best debugging tool
- Serial monitor shows detailed debug output

## Quick Reference

**Arduino Commands:**
- Compile: Ctrl+R (Cmd+R on Mac)
- Upload: Ctrl+U (Cmd+U on Mac)
- Serial Monitor: Ctrl+Shift+M (Cmd+Shift+M on Mac)

**Important Pins:**
- SDA: A4
- SCL: A5
- MPU-6050 Power: 3.3V (NOT 5V!)

**Key Constants** (in config.h):
- `STRIKE_THRESHOLD` - Adjust for sensitivity
- `IMU_READ_INTERVAL` - 10ms = 100Hz
- `DEBUG_MODE` - Set to `true` for verbose output

Good luck building your gait tracker!

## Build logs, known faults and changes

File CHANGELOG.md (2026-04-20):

# Changelog

All notable changes to this project will be documented in this file.

The format is based on [Keep a Changelog](https://keepachangelog.com/en/1.0.0/),
and this project adheres to [Semantic Versioning](https://semver.org/spec/v2.0.0.html).

## [Unreleased]

### Changed - 2026-01-14

#### Breadboard Layout Documentation Updates

Updated [docs/breadboard_layout.md](docs/breadboard_layout.md) to reflect accurate component specifications based on datasheet review:

**MP2636 Power Module Pin Labels:**
- Changed "5V OUT" to "VOUT" throughout documentation to match actual DFRobot DFR0446 breakout board pin labels
- Updated visual diagram (line 45)
- Updated connection instructions (line 105)
- Updated wiring summary table (line 142)
- Updated troubleshooting section (line 258)

**MP2636 USB Connector Clarification:**
- Corrected USB connector types based on DFRobot DFR0446 specifications
- Changed "USB-C IN" to "Micro-USB IN" for charging input (line 43)
- Added "USB-A OUT" as 5V output port (line 44)
- Clarified that USB-A is an output port (alternative to VOUT pin), not for charging (line 130)
- Updated charging instructions to specify Micro-USB only (line 128)
- Updated troubleshooting to reference correct USB ports (line 263, 265)

**Battery Wiring Diagram Fix:**
- Corrected visual diagram to accurately show battery has only 2 wires (lines 36-59)
- Fixed confusing diagram that made it appear battery negative had multiple connections
- Clarified that battery RED(+) connects to MP2636 BAT+ and battery BLACK(-) connects to MP2636 BAT-
- Common ground is established via separate jumper wire from MP2636 GND to Arduino GND (BROWN wire)
- Added note in diagram showing battery minus connection path to BAT- pin

**Rationale:**
- Review of component datasheets (Arduino Nano 33 BLE Rev2, MPU-6050, MP2636) confirmed most connections were correct
- DFRobot DFR0446 module uses "VOUT" label (connected to MP2636 IC's SYS pin) instead of generic "5V OUT"
- Module features both Micro-USB input (for charging) and USB-A output (5V out, power bank style)
- All other connections (MPU-6050 to Arduino, battery connections) verified as correct

### References
- DFRobot MP2636 Product Page: https://www.dfrobot.com/product-1613.html
- Component datasheets reviewed in `/Scratch` directory

---

### Changed - 2026-02-23

#### Firmware Activation and Bug Fixes

**imu_sensor.cpp - Activated real library code:**
- Uncommented Adafruit MPU6050 and Adafruit Sensor library includes
- Activated real `initIMU()` with proper error handling and sensor configuration
- Activated real `calibrateIMU()` with 100-sample gyroscope offset averaging
- Activated real `readIMUData()` with unit conversions (m/s² to g's, rad/s to deg/s)
- Fixed swing angle tracking - changed from `gz * dt` (near-zero per sample) to `abs(pitch)` (accumulated angle)
- Added periodic debug output for pitch and maxSwingAngle values

**ble_comms.cpp - Activated real library code:**
- Uncommented ArduinoBLE library include
- Activated BLE service and all four characteristics (stride, cadence, strike type, battery)
- Activated `initBLE()`, connection handling, and all characteristic update functions

**gait_detection.cpp - Bug fixes:**
- Fixed peak detection logic - moved `lastAz` declaration outside threshold block so deceleration is correctly detected
- Removed premature `resetSwingAngle()` call from inside `detectFootStrike()` to prevent clearing angle before stride calculation

**gait_tracker.ino - Bug fixes:**
- Added IMU streaming debug output (controlled by `ENABLE_IMU_STREAM` flag)
- Moved `resetSwingAngle()` to after `calculateStrideLength()` so swing angle is captured correctly

**config.h - Tuning:**
- Lowered `STRIKE_THRESHOLD` from 2.0g to 1.5g for better desk-tap detection during testing
- Added `ENABLE_IMU_STREAM` debug flag for raw accelerometer output
- Set `DEBUG_MODE` to false for clean production output

#### iOS App - Initial Implementation
Created complete SwiftUI iOS companion app in `GaitTracker/`:
- `GaitTrackerApp.swift` - App entry point with tab navigation
- `Models/GaitMetrics.swift` - Data types for metrics and strike classification
- `Models/RunSession.swift` - Active run tracking with timer and step counting
- `Managers/BLEManager.swift` - CoreBluetooth wrapper matching Arduino firmware UUIDs
- `Managers/DataManager.swift` - Run history persistence via UserDefaults
- `Views/ConnectionView.swift` - BLE device scanning and pairing screen
- `Views/DashboardView.swift` - Live metrics display with run controls
- `Views/HistoryView.swift` - Past runs list with CSV export
- `Views/SettingsView.swift` - Leg length calibration and preferences

**iOS Bug Fixes:**
- Added `import Combine` to `DataManager.swift` to resolve `ObservableObject` conformance error
- Added `import Combine` to `RunSession.swift` for same reason
- Added `import UIKit` to `HistoryView.swift` for `UIActivityViewController` (share sheet)

#### Test Sketches
- Created `test_sketches/imu_ble_test/imu_ble_test.ino` - Combined IMU + BLE test sketch
- Verified MPU-6050 I2C communication at address 0x68
- Verified BLE advertising and connection via nRF Connect app
- Verified foot strike detection, cadence calculation, and stride length output

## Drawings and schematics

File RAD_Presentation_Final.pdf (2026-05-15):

# RAD

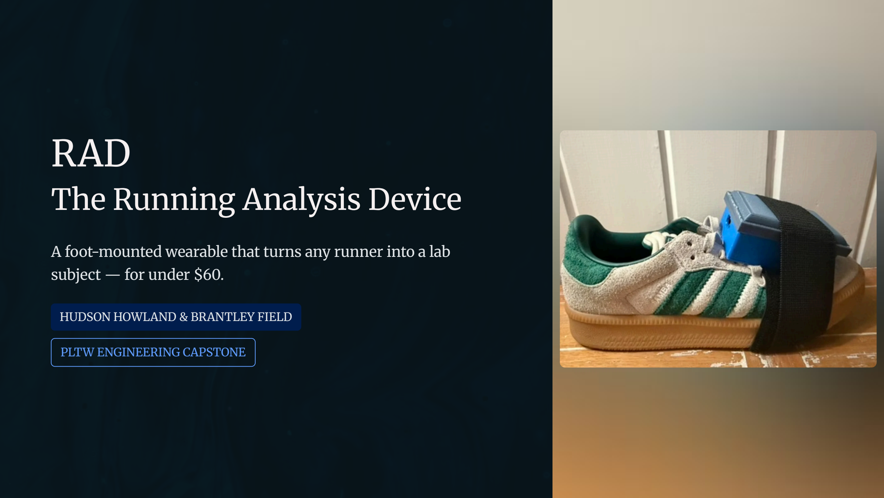
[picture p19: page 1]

# The Rě±±u±g A±a ōÿuÿ Deļuce

A f¿¿č-«¿ě±čed Łeañab e čhač čěñ±ÿ a±ō ñě±±eñ u±č¿ a ab ÿěb ecč 4 f¿ñ ě±deñ $60.

HUDSON HOWLAND & BRANTLEY FIELD

PLTW ENGINEERING CAPSTONE

# Rě±±u±g uÿ bñea u±g čhe

ée¿é e Łh¿ ¿ļe uč.

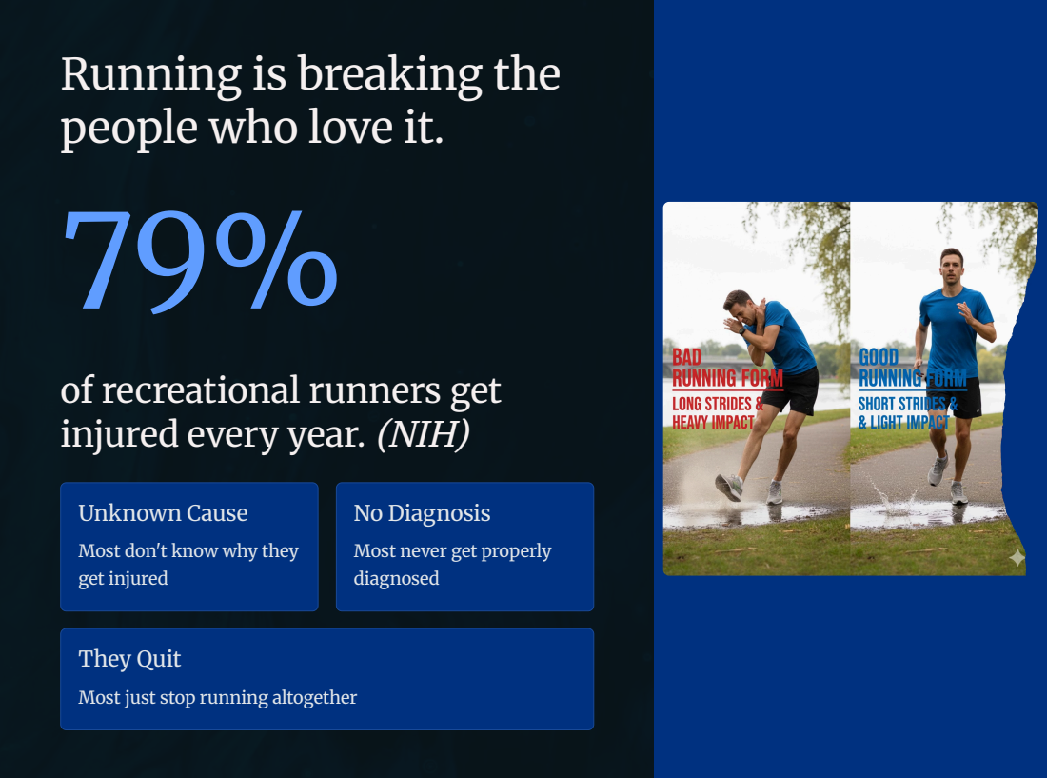
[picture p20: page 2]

¿f ñecñeaču¿±a ñě±±eñÿ geč
u± ěñed eļeñō ōeañ. (NIH)

U± ±¿Ł± Caěÿe
M¿ÿč d¿±'č ±¿Ł Łhō čheō
geč u± ěñed

N¿ Duag±¿ÿuÿ
M¿ÿč ±eļeñ geč éñ¿éeñ ō
duag±¿ÿed

Theō Qěuč
M¿ÿč ěÿč ÿč¿é ñě±±u±g a č¿gečheñ

Ič'ÿ ±¿č bad ěc . Ič'ÿ bad f¿ñ«.

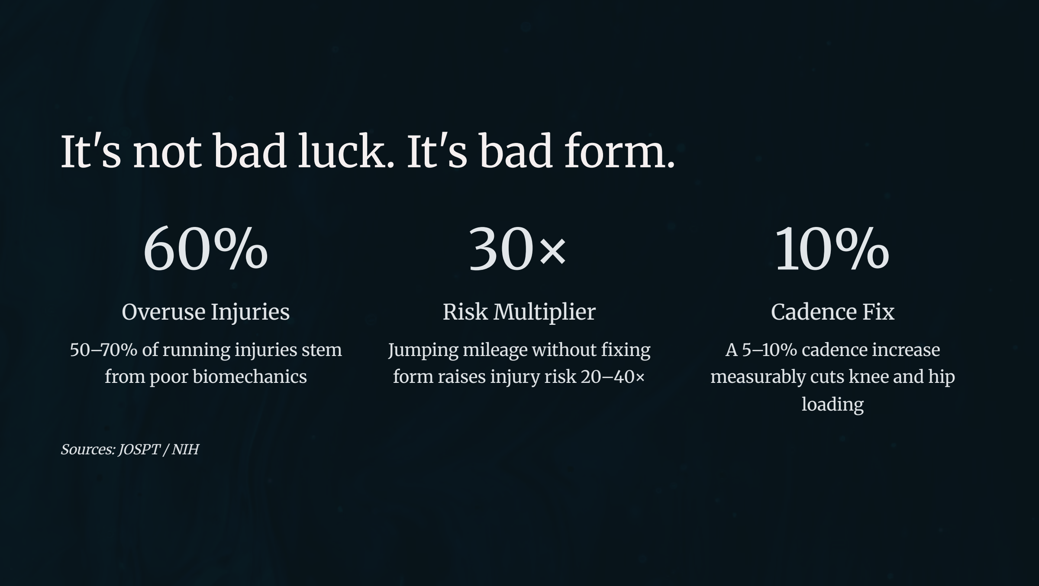
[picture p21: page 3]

60%

### Oļeñěÿe I± ěñueÿ

50370% ¿f ñě±±u±g u± ěñueÿ ÿče« fñ¿« é¿¿ñ bu¿«echa±ucÿ

30×

### Ruÿ Mě čué ueñ

Jě«éu±g «u eage Łučh¿ěč fuŊu±g f¿ñ« ñauÿeÿ u± ěñō ñuÿ 20340×

10%

### Cade±ce FuŊ

A 5310% cade±ce u±cñeaÿe
«eaÿěñab ō cěčÿ ±ee a±d hué ¿adu±g

S¿ěñceÿ: JOSPT / NIH

# The fuŊ eŊuÿčÿ. Ič'ÿ ¿c ed

behu±d a éaōŁa .

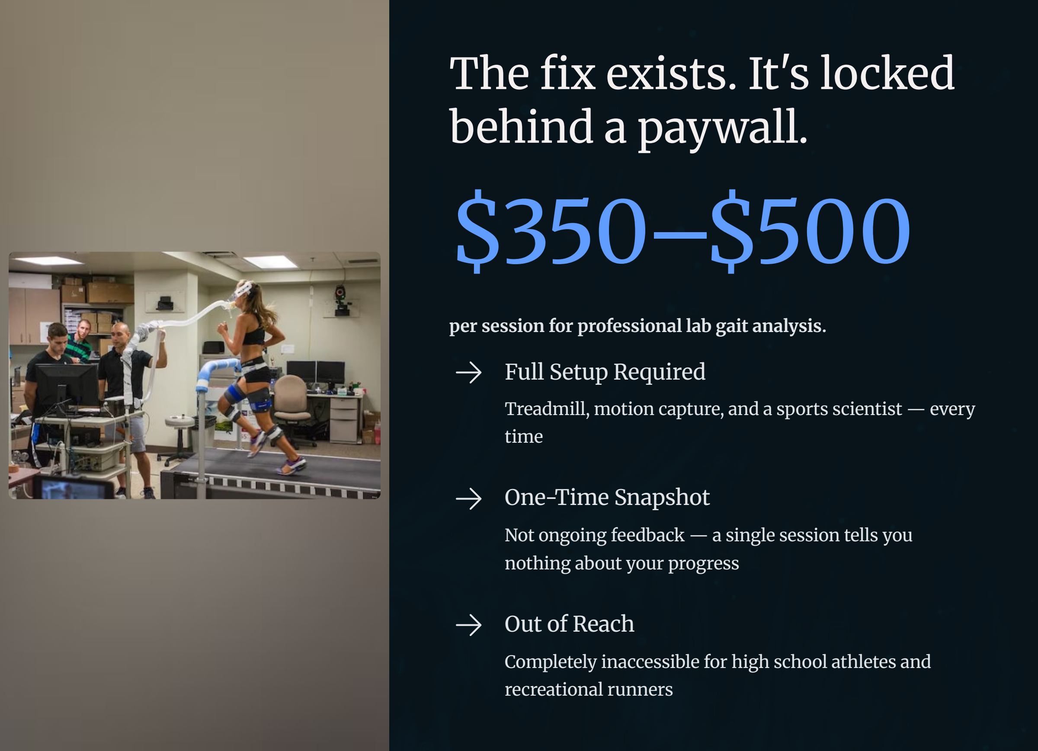
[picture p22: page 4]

$3503$500

per session for professional lab gait analysis.

### Fě Sečěé Reïěuñed

Tñead«u , «¿ču¿± caéčěñe, a±d a ÿé¿ñčÿ ÿcue±čuÿč 4 eļeñō ču«e

### O±e-Tu«e S±aéÿh¿č

N¿č ¿±g¿u±g feedbac 4 a ÿu±g e ÿeÿÿu¿± če ÿ ō¿ě ±¿čhu±g ab¿ěč ō¿ěñ éñ¿gñeÿÿ

### Oěč ¿f Reach

C¿«é eče ō u±acceÿÿub e f¿ñ hugh ÿch¿¿ ačh ečeÿ a±d ñecñeaču¿±a ñě±±eñÿ

The c¿«éečuču¿± uÿ±'č c¿«éeču±g.

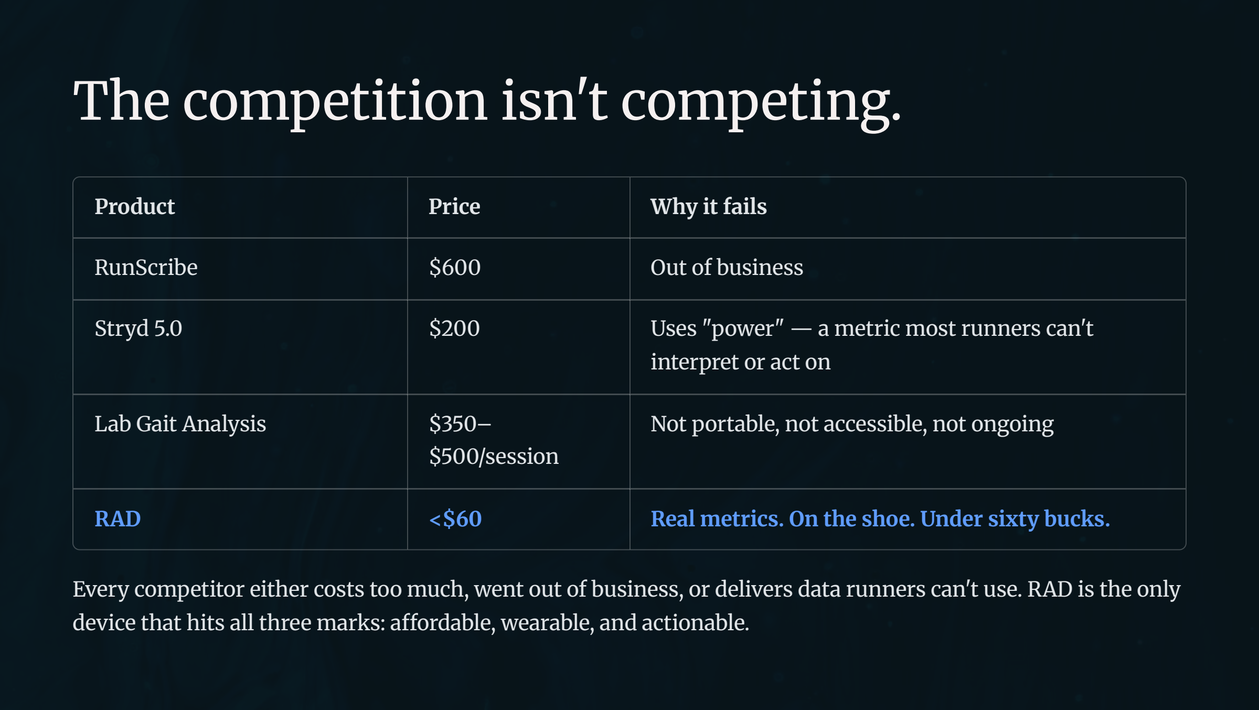
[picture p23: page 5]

Pñ¿děcč | Pñuce | Whō uč fau ÿ
Rě±Scñube | $600 | Oěč ¿f běÿu±eÿÿ
Sčñōd 5.0 | $200 | Uÿeÿ "é¿Łeñ" 4 a «ečñuc «¿ÿč ñě±±eñÿ ca±'č u±čeñéñeč ¿ñ acč ¿±
Lab Gauč A±a ōÿuÿ | $3503 $500/ÿeÿÿu¿± | N¿č é¿ñčab e, ±¿č acceÿÿub e, ±¿č ¿±g¿u±g
RAD | <$60 | Rea «ečñucÿ. O± čhe ÿh¿e. U±deñ ÿuŊčō běc ÿ.

Eļeñō c¿«éečuč¿ñ eučheñ c¿ÿčÿ č¿¿ «ěch, Łe±č ¿ěč ¿f běÿu±eÿÿ, ¿ñ de uļeñÿ dača ñě±±eñÿ ca±'č ěÿe. RAD uÿ čhe ¿± ō deļuce čhač hučÿ a čhñee «añ ÿ: aff¿ñdab e, Łeañab e, a±d acču¿±ab e.

Meeč RAD.

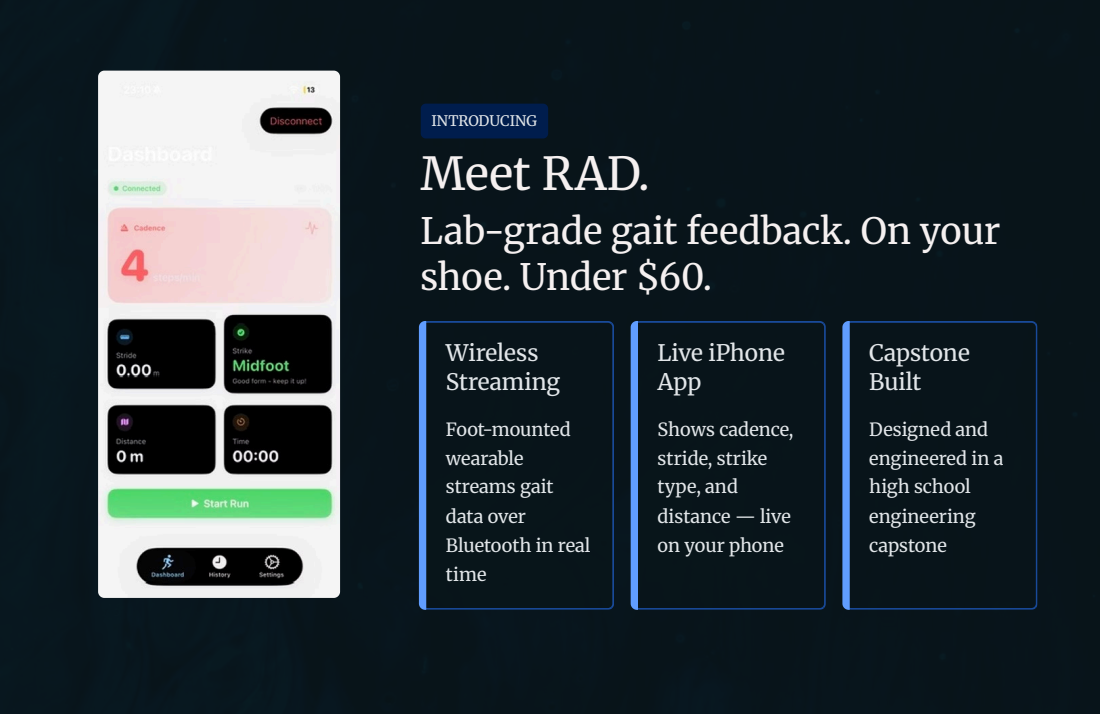
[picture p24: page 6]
Caéÿč¿±e Běu č; Deÿug±ed a±d e±gu±eeñed u± a hugh ÿch¿¿ e±gu±eeñu±g caéÿč¿±e

INTRODUCING
Lab-gñade gauč feedbac . O± ō¿ěñ
ÿh¿e. U±deñ $60.

Wuñe eÿÿ
Sčñea«u±g
F¿¿č-«¿ě±čed
Łeañab e
ÿčñea«ÿ gauč
dača ¿ļeñ
B ěeč¿¿čh u± ñea

Luļe uPh¿±e
Aéé
Sh¿Łÿ cade±ce,
ÿčñude, ÿčñu e
čōée, a±d
duÿča±ce 4 uļe

# Běu č f¿ñ čhe ñě±±eñÿ ±¿

¿±e'ÿ «eaÿěñu±g.

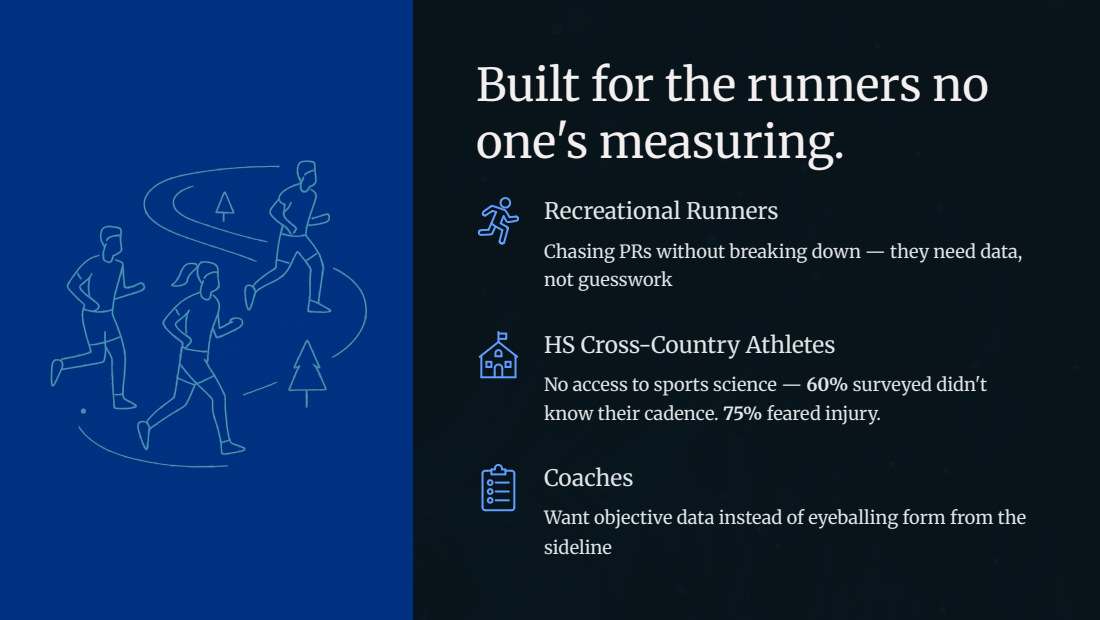
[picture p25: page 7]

Recñeaču¿±a Rě±±eñÿ
Chaÿu±g PRÿ Łučh¿ěč bñea u±g d¿Ł± 4 čheō ±eed dača,
±¿č gěeÿÿŁ¿ñ
HS Cñ¿ÿÿ-C¿ě±čñō Ačh ečeÿ
N¿ acceÿÿ č¿ ÿé¿ñčÿ ÿcue±ce 4 60% ÿěñļeōed dud±'č
±¿Ł čheuñ cade±ce. 75% feañed u± ěñō.
C¿acheÿ
Wa±č ¿b ecčuļe dača u±ÿčead ¿f eōeba u±g f¿ñ« fñ¿« čhe
ÿude u±e

Fuļe «ečñucÿ. Eļeñō ÿčeé. I± ñea ču«e.

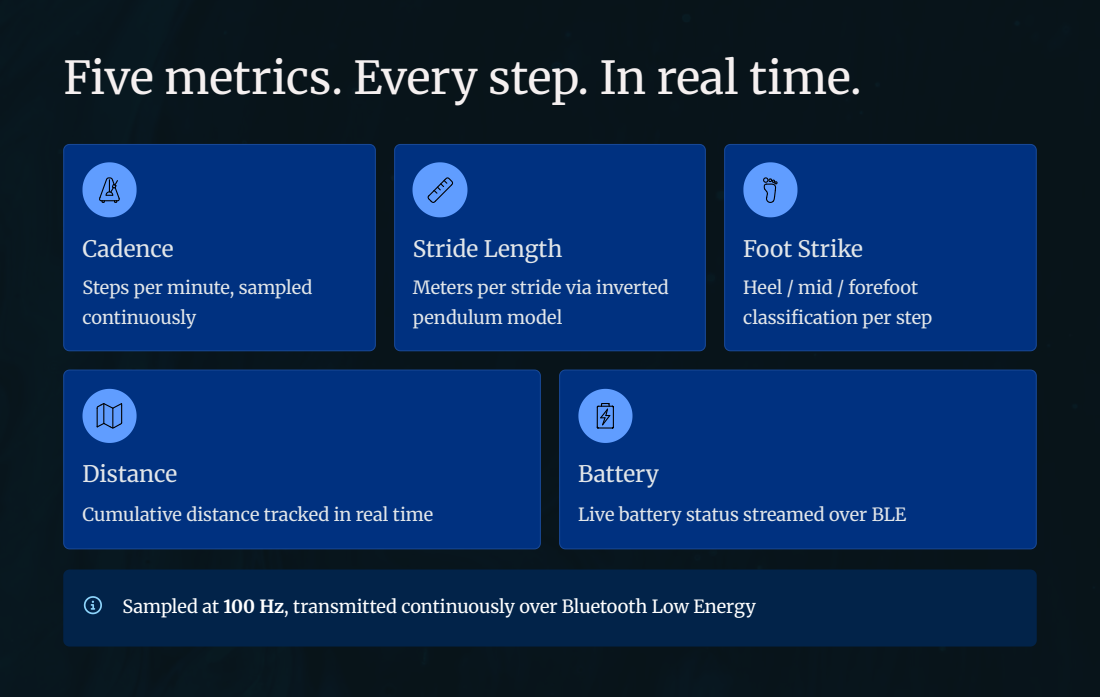
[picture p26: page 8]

Cade±ce
Sčeéÿ éeñ «u±ěče, ÿa«é ed

Sčñude Le±gčh
Mečeñÿ éeñ ÿčñude ļua u±ļeñčed

F¿¿č Sčñu e
Hee / «ud / f¿ñef¿¿č
c aÿÿufucaču¿± éeñ ÿčeé

Duÿča±ce
Cě«ě ačuļe duÿča±ce čñac ed u± ñea ču«e

Baččeñō
Luļe baččeñō ÿčačěÿ ÿčñea«ed ¿ļeñ BLE

Sa«é ed ač 100 Hz, čña±ÿ«uččed c¿±ču±ě¿ěÿ ō ¿ļeñ B ěeč¿¿čh L¿Ł E±eñgō

H¿Ł uč Ł¿ñ ÿ.

# Se±ÿ¿ñ ³ MCU ³ BLE ³ uPh¿±e

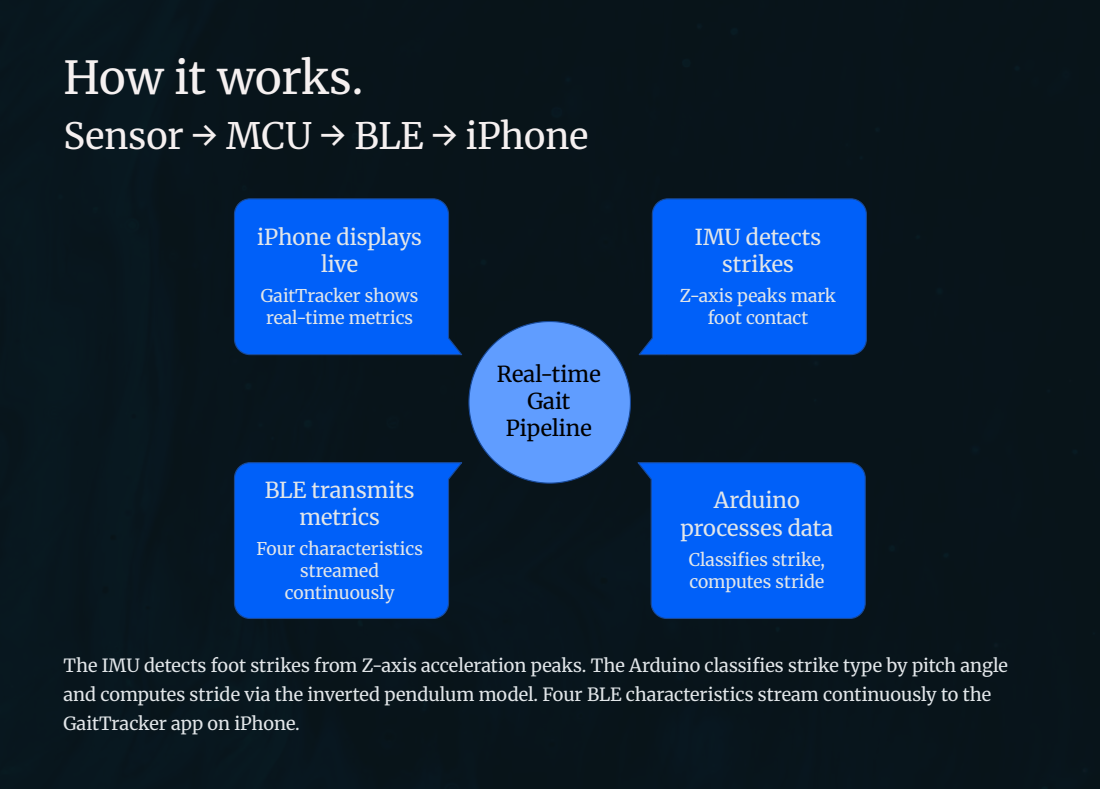
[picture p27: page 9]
Real-time Gait Pipeline

uPh¿±e duÿé aōÿ
uļe
GaučTñac eñ ÿh¿Łÿ
ñea -ču«e «ečñucÿ

IMU dečecčÿ
ÿčñu eÿ
Z-aŊuÿ éea ÿ «añ
f¿¿č c¿±čacč

BLE čña±ÿ«učÿ
«ečñucÿ
F¿ěñ chañacčeñuÿčucÿ
ÿčñea«ed

Añděu±¿
éñ¿ceÿÿeÿ dača
C aÿÿufueÿ ÿčñu e,
c¿«éěčeÿ ÿčñude

The IMU dečecčÿ f¿¿č ÿčñu eÿ fñ¿« Z-aŊuÿ acce eñaču¿± éea ÿ. The Añděu±¿ c aÿÿufueÿ ÿčñu e čōée bō éučch a±g e
a±d c¿«éěčeÿ ÿčñude ļua čhe u±ļeñčed ée±dě ě« «¿de . F¿ěñ BLE chañacčeñuÿčucÿ ÿčñea« c¿±ču±ě¿ěÿ ō č¿ čhe
GaučTñac eñ aéé ¿± uPh¿±e.

The hañdŁañe.

# ~$55 BOM

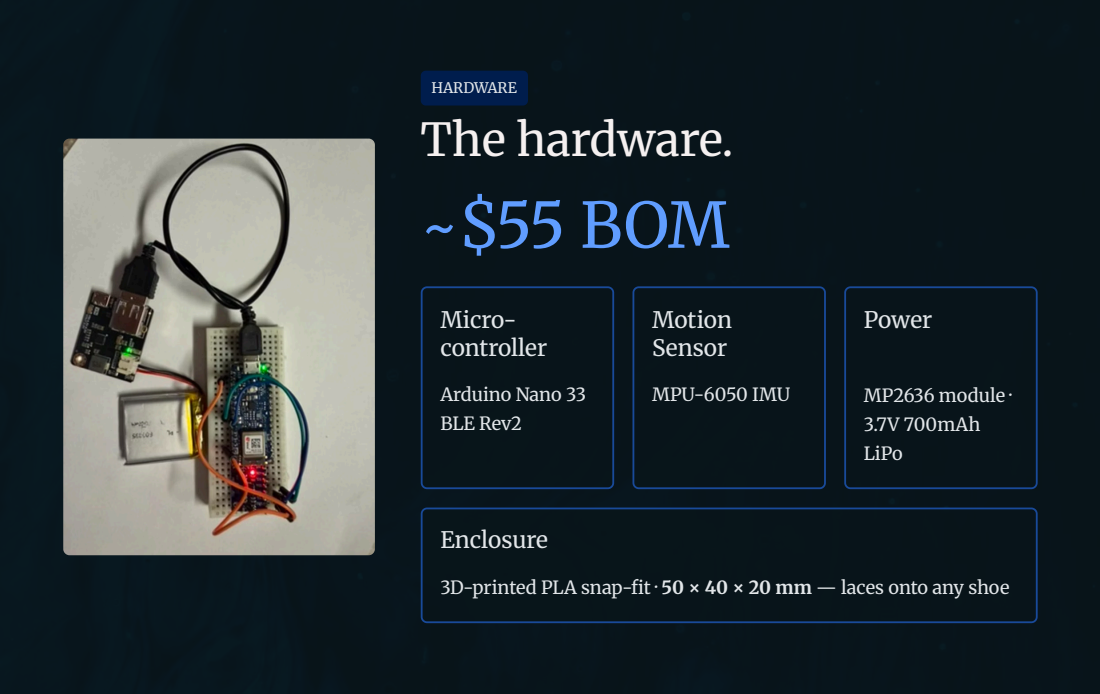
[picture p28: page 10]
HARDWARE; Mucñ¿- c¿±čñ¿ eñ; Añděu±¿ Na±¿ 33 BLE Reļ2; MPU-6050 IMU; P¿Łeñ; MP2636 «¿dě e · 3.7V 700«Ah LuP¿

E±c ¿ÿěñe
3D-éñu±čed PLA ÿ±aé-fuč · 50 × 40 × 20 mm 4 aceÿ ¿±č¿ a±ō ÿh¿e

The fuñ«Łañe.

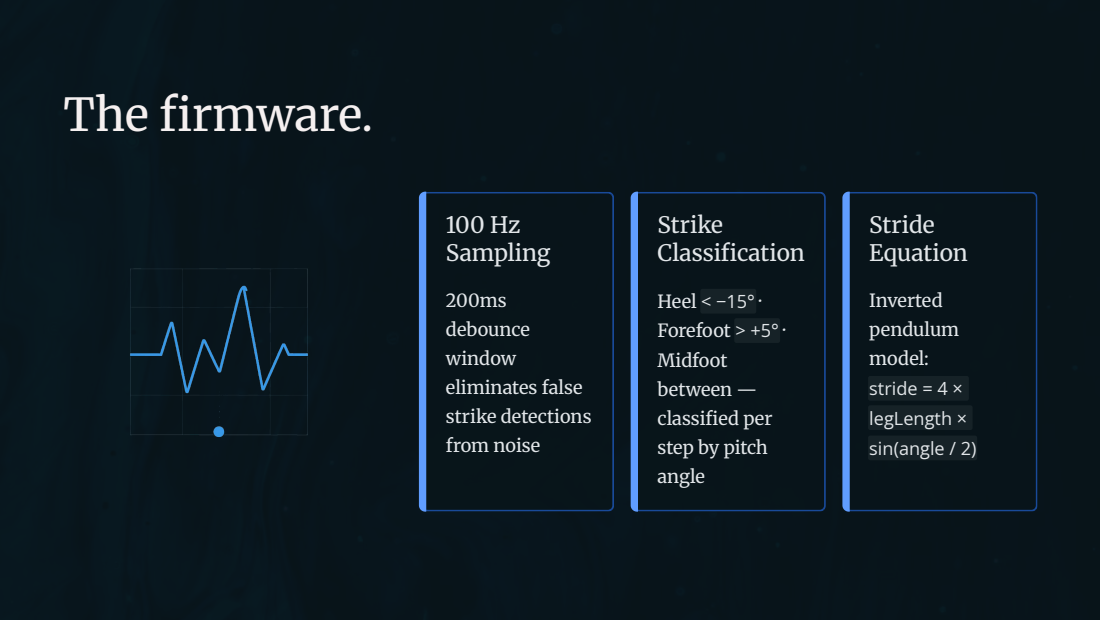
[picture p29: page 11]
Sčñu e C aÿÿufucaču¿±; Hee < 215° · F¿ñef¿¿č > +5° · Mudf¿¿č bečŁee± 4 c aÿÿufued éeñ ÿčeé bō éučch a±g e; Sčñude Eïěaču¿±; I±ļeñčed ée±dě ě« «¿de : stride = 4 × legLength × sin(angle / 2)

deb¿ě±ce
e u«u±ačeÿ fa ÿe
ÿčñu e dečecču¿±ÿ
fñ¿« ±¿uÿe

The aéé.

# GaučTñac eñ 4 SŁufč / SŁufčUI

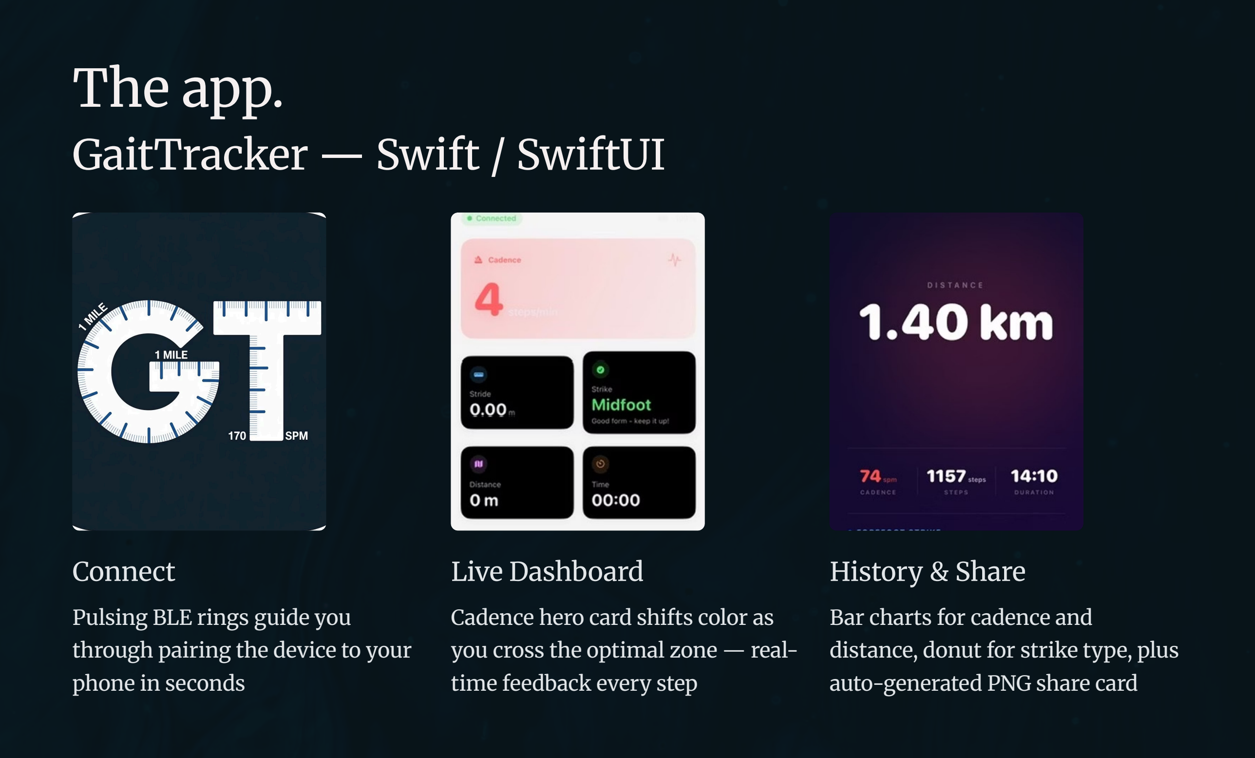
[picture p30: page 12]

### C¿±±ecč

Pě ÿu±g BLE ñu±gÿ gěude ō¿ě čhñ¿ěgh éauñu±g čhe deļuce č¿ ō¿ěñ éh¿±e u± ÿec¿±dÿ

### Luļe Daÿhb¿añd

Cade±ce heñ¿ cañd ÿhufčÿ c¿ ¿ñ aÿ ō¿ě cñ¿ÿÿ čhe ¿éču«a ś¿±e 4 ñea -ču«e feedbac eļeñō ÿčeé

### Huÿč¿ñō & Shañe

Bañ chañčÿ f¿ñ cade±ce a±d duÿča±ce, d¿±ěč f¿ñ ÿčñu e čōée, é ěÿ aěč¿-ge±eñačed PNG ÿhañe cañd

# Rea -W¿ñ d Teÿč Reÿě čÿ

1.40 «

### Duÿča±ce Rec¿ñded

Deļuce «eaÿěñe«e±č (acčěa : 0.84 «)

1,157

### Sčeéÿ C¿ě±čed

T¿ča ÿčeéÿ děñu±g ha f-«u e Ła

14:10

### Děñaču¿±

Tu«e e aéÿed děñu±g čeÿč

# 74 ÿé«

### Cade±ce

Aļeñage ÿčeéÿ éeñ «u±ěče
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

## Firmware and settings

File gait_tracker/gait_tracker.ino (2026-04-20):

/*
 * Gait Tracker - Main Sketch
 *
 * Running gait analysis device for Arduino Nano 33 BLE Rev2
 * Tracks stride length, foot strike patterns, and cadence
 *
 * Hardware:
 * - Arduino Nano 33 BLE Rev2
 * - MPU-6050 IMU (I2C: SDA=A4, SCL=A5)
 * - MP2636 Power Module + 3.7V LiPo Battery
 *
 * Author: Hudson's Projects
 * Date: 2026-01-13
 */

#include "config.h"
#include "imu_sensor.h"
#include "gait_detection.h"
#include "stride_length.h"
#include "cadence.h"
#include "ble_comms.h"
#include "power_mgmt.h"

// Timing variables
unsigned long lastIMURead = 0;
unsigned long lastCadenceUpdate = 0;
unsigned long lastBatteryUpdate = 0;

void setup() {
  // Initialize serial for debugging
  Serial.begin(115200);
  while (!Serial && millis() < 3000); // Wait up to 3 seconds for serial

  Serial.println("=== Gait Tracker Starting ===");

  // Initialize all modules
  Serial.println("Initializing IMU...");
  initIMU();

  Serial.println("Calibrating IMU...");
  calibrateIMU();

  Serial.println("Initializing BLE...");
  initBLE();

  Serial.println("Initializing Power Management...");
  initPowerManagement();

  Serial.println("=== Initialization Complete ===");
  Serial.println("Device ready. Waiting for BLE connection...");
}

void loop() {
  unsigned long currentTime = millis();

  // Read IMU data at 100Hz (every 10ms)
  if (currentTime - lastIMURead >= IMU_READ_INTERVAL) {
    lastIMURead = currentTime;

    float ax, ay, az, gx, gy, gz;
    readIMUData(ax, ay, az, gx, gy, gz);

    // Stream raw IMU values for debugging
    if (ENABLE_IMU_STREAM) {
      Serial.print("az: ");
      Serial.print(az, 3);
      Serial.print("g | total: ");
      Serial.print(sqrt(ax*ax + ay*ay + az*az), 3);
      Serial.println("g");
    }

    // Update orientation estimation
    updateOrientation();

    // Process gait detection
    if (detectFootStrike(az)) {
      // Classify strike type based on pitch angle
      StrikeType strike = classifyStrike(ax, ay, az, getPitchAngle());

      // Calculate stride length then reset swing angle for next stride
      float stride = calculateStrideLength(getMaxSwingAngle());
      resetSwingAngle();

      // Increment step count
      incrementStepCount();

      // Update BLE characteristics immediately
      updateBLEMetrics(stride, strike);

      // Debug output
      Serial.print("Strike detected: ");
      Serial.print(strike == HEEL ? "HEEL" : (strike == MIDFOOT ? "MIDFOOT" : "FOREFOOT"));
      Serial.print(" | Stride: ");
      Serial.print(stride, 2);
      Serial.println(" m");
    }
  }

  // Update cadence every second
  if (currentTime - lastCadenceUpdate >= CADENCE_UPDATE_INTERVAL) {
    lastCadenceUpdate = currentTime;

    float cadence = calculateCadence();
    updateBLECadence(cadence);

    // Debug output
    if (cadence > 0) {
      Serial.print("Cadence: ");
      Serial.print(cadence, 0);
      Serial.println(" steps/min");
    }
  }

  // Update battery level every 30 seconds
  if (currentTime - lastBatteryUpdate >= BATTERY_UPDATE_INTERVAL) {
    lastBatteryUpdate = currentTime;

    uint8_t batteryPercent = getBatteryPercent();
    updateBLEBattery(batteryPercent);
  }

  // Handle BLE connection events
  handleBLEConnection();

  // Power management - disabled until after presentation
  // if (isStationary() && getTimeSinceLastMotion() > IDLE_TIMEOUT) {
  //   enterLowPowerMode();
  // }

  // Small delay to maintain 100Hz loop rate
  delay(1);
}

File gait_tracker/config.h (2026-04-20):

/*
 * Gait Tracker - Configuration Header
 *
 * Central configuration file for all constants and settings
 */

#ifndef CONFIG_H
#define CONFIG_H

// ===== Hardware Configuration =====
#define MPU6050_ADDRESS 0x68  // I2C address of MPU-6050
#define SDA_PIN A4            // I2C SDA pin
#define SCL_PIN A5            // I2C SCL pin

// ===== Timing Configuration =====
#define IMU_READ_INTERVAL 10           // Read IMU every 10ms (100Hz)
#define CADENCE_UPDATE_INTERVAL 1000   // Update cadence every 1 second
#define BATTERY_UPDATE_INTERVAL 30000  // Update battery every 30 seconds
#define IDLE_TIMEOUT 30000             // Enter low power after 30s of inactivity

// ===== IMU Configuration =====
#define ACCEL_RANGE 2       // Accelerometer range: ±2g
#define GYRO_RANGE 250      // Gyroscope range: ±250°/s
#define GRAVITY 9.81        // Gravity constant (m/s²)

// Complementary filter coefficient (0.0 - 1.0)
// Higher value = trust gyroscope more, lower value = trust accelerometer more
#define ALPHA 0.96

// ===== Gait Detection Configuration =====
// Foot strike detection threshold (in g's)
#define STRIKE_THRESHOLD 1.5

// Debounce time to ignore secondary peaks (ms)
#define STRIKE_DEBOUNCE 200

// Strike classification pitch angle thresholds (degrees)
#define HEEL_STRIKE_MAX -15.0    // Pitch < -15° = heel strike
#define FOREFOOT_STRIKE_MIN 5.0  // Pitch > +5° = forefoot strike
// Between these values = midfoot strike

// ===== Stride Length Configuration =====
// Default leg length (hip to ground) in meters
// User can calibrate this via iOS app
#define DEFAULT_LEG_LENGTH 0.90

// Stride length correction factor (tune based on field testing)
#define STRIDE_CORRECTION_FACTOR 1.0

// ===== Cadence Configuration =====
// Number of recent foot strikes to track for cadence calculation
#define CADENCE_BUFFER_SIZE 30

// Minimum strikes needed before calculating cadence
#define MIN_STRIKES_FOR_CADENCE 3

// ===== BLE Configuration =====
// Device name (visible during scanning)
#define BLE_DEVICE_NAME "GaitTracker"

// BLE Service UUIDs (custom UUIDs - generate your own if needed)
#define GAIT_SERVICE_UUID "19b10000-e8f2-537e-4f6c-d104768a1214"

// BLE Characteristic UUIDs
#define STRIDE_LENGTH_CHAR_UUID "19b10001-e8f2-537e-4f6c-d104768a1214"
#define CADENCE_CHAR_UUID       "19b10002-e8f2-537e-4f6c-d104768a1214"
#define STRIKE_TYPE_CHAR_UUID   "19b10003-e8f2-537e-4f6c-d104768a1214"
#define BATTERY_CHAR_UUID       "00002a19-0000-1000-8000-00805f9b34fb"  // Standard Battery Level

// BLE connection interval (ms)
#define BLE_CONNECTION_INTERVAL 15

// ===== Power Management Configuration =====
// Battery voltage divider ratio (adjust based on your circuit)
// If using 2x 10kΩ resistors: ratio = 0.5
#define BATTERY_VOLTAGE_RATIO 0.5

// Battery voltage range (3.0V empty, 4.2V full)
#define BATTERY_EMPTY_VOLTAGE 3.0
#define BATTERY_FULL_VOLTAGE 4.2

// Analog pin for battery voltage reading
#define BATTERY_PIN A0

// ===== Debug Configuration =====
// Set to true to enable verbose serial debug output
#define DEBUG_MODE false

// Set to true to enable IMU data streaming over BLE (for debugging)
#define ENABLE_IMU_STREAM false

// ===== Data Types =====
// Strike type enumeration
enum StrikeType {
  HEEL = 0,
  MIDFOOT = 1,
  FOREFOOT = 2
};

// Stride state machine
enum StrideState {
  SWING,
  STRIKE,
  STANCE
};

#endif // CONFIG_H

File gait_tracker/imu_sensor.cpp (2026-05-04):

/*
 * IMU Sensor Module - Implementation
 *
 * Handles MPU-6050 initialization, calibration, and data reading
 */

#include "imu_sensor.h"
#include "config.h"
#include <Wire.h>
#include <Adafruit_MPU6050.h>
#include <Adafruit_Sensor.h>

// Global variables
float pitch = 0.0;
float roll = 0.0;
float correctedPitch = 0.0;
float pitchOffset = 0.0;
float maxSwingAngle = 0.0;
float gyroOffsetX = 0.0;
float gyroOffsetY = 0.0;
float gyroOffsetZ = 0.0;

unsigned long lastUpdateTime = 0;
unsigned long lastMotionTime = 0;

Adafruit_MPU6050 mpu;

void initIMU() {
  // Initialize I2C
  Wire.begin();

  if (!mpu.begin(MPU6050_ADDRESS)) {
    Serial.println("Failed to find MPU6050 chip");
    while (1) {
      delay(10);
    }
  }
  Serial.println("MPU6050 Found!");

  // Set accelerometer range
  mpu.setAccelerometerRange(MPU6050_RANGE_2_G);

  // Set gyroscope range
  mpu.setGyroRange(MPU6050_RANGE_250_DEG);

  // Set filter bandwidth
  mpu.setFilterBandwidth(MPU6050_BAND_21_HZ);

  Serial.println("MPU6050 initialized successfully");

  lastUpdateTime = millis();
  lastMotionTime = millis();
}

void calibrateIMU() {
  Serial.println("Calibrating IMU... Keep device still on flat surface");

  const int numSamples = 100;
  float sumGX = 0, sumGY = 0, sumGZ = 0;

  for (int i = 0; i < numSamples; i++) {
    sensors_event_t a, g, temp;
    mpu.getEvent(&a, &g, &temp);

    sumGX += g.gyro.x;
    sumGY += g.gyro.y;
    sumGZ += g.gyro.z;

    delay(10);
  }

  gyroOffsetX = sumGX / numSamples;
  gyroOffsetY = sumGY / numSamples;
  gyroOffsetZ = sumGZ / numSamples;

  Serial.print("Gyro offsets - X: ");
  Serial.print(gyroOffsetX, 4);
  Serial.print(" Y: ");
  Serial.print(gyroOffsetY, 4);
  Serial.print(" Z: ");
  Serial.println(gyroOffsetZ, 4);

  // Warm up complementary filter so pitch converges to the actual mounting angle
  Serial.println("Measuring mounting angle... Keep device on shoe, hold still");
  lastUpdateTime = millis();
  for (int i = 0; i < 200; i++) {
    updateOrientation();
    delay(10);
  }

  // Average pitch over 100 samples to get stable resting offset
  float sumPitch = 0;
  for (int i = 0; i < 100; i++) {
    updateOrientation();
    sumPitch += pitch;
    delay(10);
  }
  pitchOffset = sumPitch / 100;

  Serial.print("Mounting angle offset: ");
  Serial.print(pitchOffset, 1);
  Serial.println(" degrees");
  Serial.println("Calibration complete");
}

void readIMUData(float &ax, float &ay, float &az, float &gx, float &gy, float &gz) {
  sensors_event_t accel, gyro, temp;
  mpu.getEvent(&accel, &gyro, &temp);

  // Convert to appropriate units
  ax = accel.acceleration.x / GRAVITY;  // Convert to g's
  ay = accel.acceleration.y / GRAVITY;
  az = accel.acceleration.z / GRAVITY;

  // Apply gyro offsets and convert to degrees/sec
  gx = (gyro.gyro.x - gyroOffsetX) * 57.2958; // rad/s to deg/s
  gy = (gyro.gyro.y - gyroOffsetY) * 57.2958;
  gz = (gyro.gyro.z - gyroOffsetZ) * 57.2958;
}

void updateOrientation() {
  unsigned long currentTime = millis();
  float dt = (currentTime - lastUpdateTime) / 1000.0; // Convert to seconds
  lastUpdateTime = currentTime;

  // Get current sensor data
  float ax, ay, az, gx, gy, gz;
  readIMUData(ax, ay, az, gx, gy, gz);

  // Calculate pitch and roll from accelerometer
  float accelPitch = atan2(ay, sqrt(ax * ax + az * az)) * 57.2958;
  float accelRoll = atan2(-ax, az) * 57.2958;

  // Integrate gyroscope for pitch and roll
  pitch += gy * dt;
  roll += gx * dt;

  // Apply complementary filter
  pitch = ALPHA * pitch + (1.0 - ALPHA) * accelPitch;
  roll = ALPHA * roll + (1.0 - ALPHA) * accelRoll;

  // Remove static mounting angle so pitch is relative to the shoe's resting position
  correctedPitch = pitch - pitchOffset;

  // Track maximum swing angle using corrected pitch
  float currentSwingAngle = abs(correctedPitch);
  if (currentSwingAngle > maxSwingAngle) {
    maxSwingAngle = currentSwingAngle;
  }

  // Update motion detection
  float totalAccel = sqrt(ax * ax + ay * ay + az * az);
  if (abs(totalAccel - 1.0) > 0.1) { // More than 0.1g deviation from stationary
    lastMotionTime = currentTime;
  }

  if (DEBUG_MODE) {
    static int debugCounter = 0;
    if (++debugCounter >= 20) { // Print every 20 reads = every 200ms
      debugCounter = 0;
      Serial.print("Pitch: "); Serial.print(pitch, 1);
      Serial.print("° | MaxSwing: "); Serial.print(maxSwingAngle, 1);
      Serial.println("°");
    }
  }
}

float getPitchAngle() {
  return correctedPitch;
}

float getRollAngle() {
  return roll;
}

float getMaxSwingAngle() {
  return maxSwingAngle;
}

void resetSwingAngle() {
  maxSwingAngle = 0.0;
}

bool isStationary() {
  return (millis() - lastMotionTime) > 5000; // Stationary if no motion for 5 seconds
}

unsigned long getTimeSinceLastMotion() {
  return millis() - lastMotionTime;
}

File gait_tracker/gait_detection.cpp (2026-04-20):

/*
 * Gait Detection Module - Implementation
 *
 * Handles foot strike detection and classification
 */

#include "gait_detection.h"
#include "imu_sensor.h"

// Global variables
StrideState currentState = SWING;
unsigned long lastStrikeTime = 0;
float peakAcceleration = 0.0;

bool detectFootStrike(float az) {
  unsigned long currentTime = millis();

  // Calculate magnitude of vertical acceleration
  float verticalAccel = abs(az);

  // Track peak acceleration during potential strike
  if (verticalAccel > peakAcceleration) {
    peakAcceleration = verticalAccel;
  }

  // Debounce: ignore strikes too close together
  if (currentTime - lastStrikeTime < STRIKE_DEBOUNCE) {
    return false;
  }

  static float lastAz = 0.0;

  // Detect strike when acceleration exceeds threshold
  if (verticalAccel > STRIKE_THRESHOLD) {
    // Confirm it's a peak (not just rising edge)
    // by checking if we're starting to decelerate
    if (verticalAccel < lastAz) { // Deceleration started - we passed the peak
      lastStrikeTime = currentTime;
      peakAcceleration = 0.0;
      lastAz = 0.0;

      if (DEBUG_MODE) {
        Serial.println(">>> Foot strike detected <<<");
      }

      return true;
    }
  }

  lastAz = verticalAccel;
  return false;
}

StrikeType classifyStrike(float ax, float ay, float az, float pitch) {
  // Classify based on pitch angle at moment of impact
  // Negative pitch = heel down (heel strike)
  // Near-zero pitch = flat foot (midfoot strike)
  // Positive pitch = toe down (forefoot strike)

  StrikeType type;

  if (pitch < HEEL_STRIKE_MAX) {
    type = HEEL;
  } else if (pitch > FOREFOOT_STRIKE_MIN) {
    type = FOREFOOT;
  } else {
    type = MIDFOOT;
  }

  if (DEBUG_MODE) {
    Serial.print("Strike classified as: ");
    Serial.print(type == HEEL ? "HEEL" : (type == MIDFOOT ? "MIDFOOT" : "FOREFOOT"));
    Serial.print(" (pitch: ");
    Serial.print(pitch, 1);
    Serial.println("°)");
  }

  return type;
}

void updateStrideState() {
  // Simple state machine for stride phases
  // This can be expanded for more sophisticated gait analysis

  switch (currentState) {
    case SWING:
      // Transition to STRIKE when foot strike is detected
      // (handled in detectFootStrike)
      break;

    case STRIKE:
      // Transition to STANCE after brief strike phase
      currentState = STANCE;
      break;

    case STANCE:
      // Transition to SWING when foot leaves ground
      // (detect by low vertical acceleration)
      // This is simplified - could use more sophisticated detection
      currentState = SWING;
      break;
  }
}

StrideState getStrideState() {
  return currentState;
}

void resetGaitDetection() {
  currentState = SWING;
  lastStrikeTime = 0;
  peakAcceleration = 0.0;
  Serial.println("Gait detection reset");
}

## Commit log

2026-01-21 CAD design
    [gait_tracker_enclosure.scad]
2026-05-15 Final portfolio and updated README reflecting completed project state
    - README rewritten from scratch: all phases marked complete, accurate repo
    structure, field test results, stakeholder evaluation summary, and
    mounting angle calibration documented
    - FINAL_PORTFOLIO.md added: full capstone portfolio covering problem statement,
    hardware, firmware, iOS app, testing results, stakeholder evaluation,
    improvement plans, and reflection
2026-05-15 Add presentation files
    - RAD_Presentation_Final.pdf: final Gamma presentation (18 slides)
    - Running analysis device - slides 14-17.pdf: original PLTW slides
    - Running analysis device - slides 14-17.pptx: editable PowerPoint source
